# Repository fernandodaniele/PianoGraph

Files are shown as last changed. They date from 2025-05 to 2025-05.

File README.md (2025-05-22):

# PianoGraph 🎹
PianoGraph is an educational hardware device designed to assist beginners in learning to play the piano. Developed as a final thesis project for the Electronic Engineering degree in 2017, PianoGraph combines visual guidance and real-time feedback to enhance the learning process.
The system works by illuminating the keys a user should press, effectively acting as a visual tutor. This allows learners to associate musical notes with their physical positions on the keyboard, helping bridge the gap between reading sheet music and hand coordination.
PianoGraph was designed with accessibility and ease of use in mind, offering an intuitive interface and support for various practice modes. It aims to make learning the piano more engaging, effective, and fun.

## 📌 Features

- LED indicators above each key for real-time guidance  
- MIDI file support for learning actual songs  
- Multiple learning modes (note-by-note, tempo control, etc.)  
- Simple and intuitive user interface  
- Designed for acoustic and digital pianos  

## 🛠️ Technologies Used

- Microcontroller-based hardware  
- MIDI protocol for song input  
- LED driver circuits  
- Embedded C/C++  
- App for song management  

## 🚀 How It Works

1. Load a MIDI song file onto the app.  
2. PianoGraph analyzes the notes and lights up the corresponding keys.  
3. The learner follows the lights and plays the notes.  
4. Optional feedback features track progress and accuracy.

## Media
[https://youtu.be/cpoeSTIPf7A ](https://youtu.be/cpoeSTIPf7A)

## 📚 Academic Context

This project was completed in 2017 as a final thesis for the Electronic Engineering program. It represents a fusion of embedded systems, human-computer interaction, and music education.

## 📃 License

This project is open-source. See the `LICENSE` file for more details.

## ✉️ Contact

For more information or collaboration inquiries:  
[Fernando E. Daniele] 
[Gonzalo Velazquez]

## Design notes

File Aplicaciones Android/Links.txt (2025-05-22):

http://programandoointentandolo.com/2014/06/como-hacer-un-explorador-de-archivos-en-android.html

http://www.aprendeandroid.com/l8/listar_archivos.htm

http://jonsegador.com/2012/02/paso-de-datos-variables-entre-actividades-android/

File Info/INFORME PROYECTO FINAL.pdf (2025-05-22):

PROYECTO FINAL

Daniele, Fernando – Velazquez, Gonzalo |
PianoGraph! | | I

Autores: Daniele, Fernando.

Velazquez, Gonzalo.

Asignatura: Proyecto Final

Profesor: Ing. Daniel Musso

Institución: U.T.N. Facultad Regional

San Francisco.

Lugar: San Francisco, Córdoba

# PianoGraph!

Sistema virtual de aprendizaje de piano.

Daniele, Fernando – Velazquez, Gonzalo |
PianoGraph! | | II

Daniele, Fernando – Velazquez, Gonzalo |
PianoGraph! | | III

RESUMEN

Aprender a tocar un instrumento musical es una actividad que requiere de un

gran esfuerzo mental, similar al de aprender un nuevo idioma. Esto desde siempre

ha fascinado a gran parte de la población, sin importar su edad o ubicación

geográfica. Según datos del Instituto Nacional de Estadística y Geografía (México),

cerca del 30% de la población mexicana toca algún instrumento musical. Este

número asciende hasta casi un 50% en Austria, ubicándose el piano como el

segundo instrumento más tocado (después de la guitarra eléctrica).

En este proyecto, hemos desarrollado una herramienta para facilitar el proceso

de aprendizaje de un instrumento en específico, el piano. Mediante una

pantalla/cortina de ledes ubicada sobre las teclas del mismo, y haciendo uso de

señales lumínicas, el dispositivo le indicará al usuario cuales teclas debe presionar

en el instante preciso en que corresponda. Mediante un microcontrolador se

decodifica cualquier canción en formato MIDI que el usuario desee aprender, y se

muestra en el dispositivo. De esta forma el usuario puede ejecutar perfectamente

cualquier canción siguiendo las instrucciones. Al finalizar la canción el dispositivo

otorga un puntaje de éxito/error obtenido, con el fin de tener una medida para auto

superarse o competir con amigos.

Palabras claves propuestas: CORTINA LED, PANTALLA LED, MIDI, PIANO,

INSTRUMENTO MUSICAL, APRENDIZAJE.

Daniele, Fernando – Velazquez, Gonzalo |
PianoGraph! | | IV

ÍNDICE

RESUMEN | IIII
ÍNDICE | IV
INTRODUCCIÓN | 1
OBJETIVOS | 4
DESCRIPCIÓN | 5
METAS | 9
JUSTIFICACIÓN | 11
ASPECTOS DE MERCADO | 12
ASPECTOS INSTITUCIONALES | 15
CONTENIDO DEL PROYECTO | 14
CONCLUSIONES | 55
APENDICE | 56
BIBLIOGRAFÍA | 57
ANEXO I | 58
ANEXO II | 60

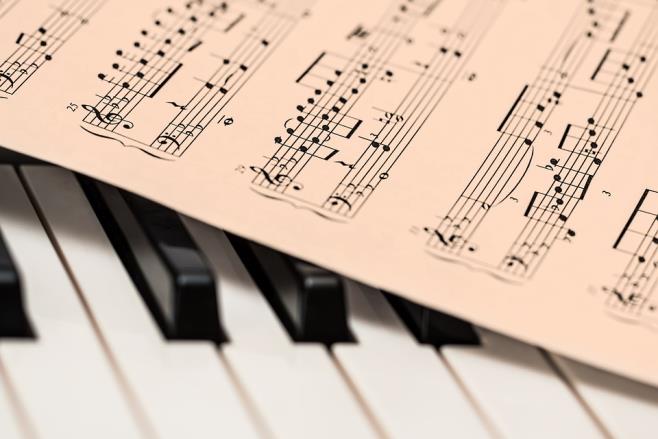
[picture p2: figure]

Ingeniería Electrónica | PianoGraph! | 1

INTRODUCCIÓN

Este proyecto nace de la necesidad personal de uno de nosotros de aprender a

tocar el piano, quien, al momento de hacerlo, se encontró con muchas dificultades,

principalmente por los actuales métodos de aprendizaje.

A grandes rasgos, existen dos métodos de aprender a ejecutar un instrumento

musical:

- Un primer método consiste en aprender la teoría musical, cómo están

compuestos los acordes, dónde se ubica cada nota en el teclado, y comenzar

a leer partituras simples, hasta eventualmente poder ejecutar partituras más

complejas. Este es un método que requiere gran dedicación y esfuerzo, ya

que se aprende verdaderamente música, se comprende lo que se está

tocando y se puede llegar a dominar el instrumento profesionalmente.

Fig.1

- Un segundo método consiste en observar a otra persona tocando la canción

deseada, memorizar cuales teclas presiona y copiar los movimientos. Esta es

una solución que no requiere de estudios ni aprendizaje de la teoría musical.

Presenta la ventaja de que en poco tiempo (quizás menos de un día), la

persona puede estar ejecutando perfectamente alguna pieza. La desventaja

es que se requiere de una solución específica para cada canción diferente

que la persona quiera aprender, ya que en cada canción se tocan diferentes

notas, la persona debe copiar diferentes movimientos.

Ingeniería Electrónica | PianoGraph! | 2

Este es un método ampliamente difundido en internet, donde se pueden

observar videos para aprender diferentes canciones, e incluso existen

aplicaciones dedicadas a este método, como Synthesia ®. Algunas personas

sólo desean poder tocar el piano sin dedicarse profesionalmente a ello, y ésta

es una solución adecuada para aprender a ejecutar canciones sin tener que

pasar quizás años estudiando música. Es por eso que optamos por

desarrollar un dispositivo que utilice este método para enseñar a los usuarios.

Fig.2 - Synthesia

El dispositivo a desarrollar constaría de una pantalla o cortina de ledes, con

tantas columnas de ledes como teclas tenga el piano/teclado. Estos ledes se

encenderán unos instantes antes del momento de que el usuario deba presionar la

nota, desde la primer fila (ubicada más alejada del piano), secuencialmente hasta la

última fila (ubicada lo más cerca de las teclas posible), que será el momento en que

se debe presionar dicha tecla.

Gracias a una interfaz y una metodología de juego sencilla cualquier persona,

de cualquier edad o educación podrá aprender a tocar el piano. Además, este

proyecto presenta un potencial enorme ya que no existe nada similar en el mercado.

Los videojuegos que utilizan el mismo principio, como Guitar Hero ® (en el que se

toca una guitarra con seis botones), o Pump It Up ® (una alfombra donde se

presionan unos indicadores luminosos con los pies al ritmo de la música), tuvieron

Ingeniería Electrónica | PianoGraph! | 3

gran aceptación y éxito, lo que indica que para las personas es fácil y divertido

entender la dinámica del juego.

Fig 3 y 4 – Videojuegos que utilizan el mismo principio

Una ventaja fundamental, es que el usuario no debería comprar un piano

específico para utilizar este sistema, sino que se puede adaptar a cualquier

piano/teclado existente.

Ingeniería Electrónica | PianoGraph! | 4

OBJETIVOS

La finalidad del proyecto es crear un dispositivo gracias al cual cualquier

persona, sin importar su edad o educación, sea capaz de aprender de manera

sencilla y divertida a tocar el piano, o instrumentos similares tales como el órgano o

teclado electrónico. El usuario debe ser capaz de elegir la melodía que desea tocar

mediante una computadora o celular. Los mismos deben estar conectados física o

inalámbricamente al dispositivo, el cual a través de una pantalla de diodos ledes

indicará en que momento presionar o soltar cada tecla del instrumento musical.

Podemos dividir el objetivo general en tres objetivos específicos:

1° Comprender el protocolo de comunicación MIDI, y a través de una conexión por

puerto MIDI mostrar las notas correspondientes en la cortina de ledes.

2° Realizar una retroalimentación desde el teclado electrónico hacia el dispositivo

para comparar lo tocado por el usuario con la melodía original.

3° Desarrollar un aplicación para celulares que realice una comunicación bluetooth

con el dispositivo para poder cargar las canciones a través del mismo y visualizar el

puntaje obtenido.

Ingeniería Electrónica | PianoGraph! | 5

DESCRIPCIÓN

El protocolo MIDI (Musical Instrument Digital Interface), es un tipo de

comunicación serial utilizado ampliamente por casi todos los instrumentos musicales

que posean la necesidad de intercambiar información entre ellos, (sintetizadores,

controladores, teclados, etc). Si tomamos como ejemplo un teclado electrónico que

tenga la posibilidad de recibir mensajes MIDI provenientes de otro instrumento o

computadora, y pueda reproducirlos por sus parlantes, lo que sucede para que ello

ocurra es lo siguiente:

1. El dispositivo emisor del mensaje envía mediante el cable MIDI una serie

de bytes, donde se encuentra especificado, por ejemplo, si es un mensaje

para encender una nota: el número de esa nota (del 0 al 127,

correspondiendo el 60 al do central de un piano), y la intensidad con la que

esa nota debe sonar (el volumen).

2. El teclado electrónico que reciba esos mensajes, tiene un banco de sonidos

almacenados, con un sonido diferente para cada una de las 128 notas

posibles, y reproducirá según indique el mensaje MIDI, una de estas notas,

hasta que llegue otro mensaje MIDI, que indique que el sonido debe cesar.

Cabe aclarar que en un mensaje MIDI no está especificado el tipo de sonido que

debe reproducirse, es decir, el dispositivo que reproduzca el sonido puede asignar el

timbre de una guitarra, de una flauta, o de cualquier instrumento que tenga cargado

en su base de datos al mensaje MIDI recibido.

De la misma manera que un teclado recibe y transforma esos mensajes MIDI a

sonido, PianoGraph! posee un microcontrolador que recibe y transforma los

mensajes MIDI en estímulos visuales (luces ledes) y asigna una columna de ledes a

cada número de nota recibido.

Cada columna se encuentra posicionada exactamente sobre cada tecla de un piano

estándar. Entonces al encenderse el primer Led de una columna, este comienza a

descender fila por fila, hasta llegar a la última fila, donde será el momento de

presionar la tecla indicada.

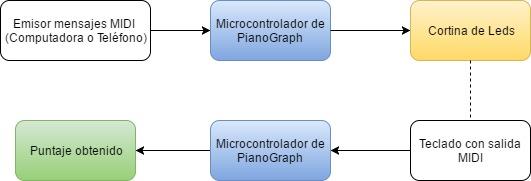
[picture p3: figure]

Ingeniería Electrónica | PianoGraph! | 6

Fig. 5 - Descripción

Las luces descenderán desde la primera fila hacia la última, desplazándose a

intervalos de tiempo iguales. Este intervalo puede ser ajustado por el usuario, cuanto

menor sea el tiempo de desplazamiento, más rápida será la velocidad con la que las

luces llegan hasta la última fila, con lo que el tiempo de reacción del usuario deberá

ser también menor. Al disminuir el tiempo de desplazamiento lo que se logra es

tener una mayor resolución de las notas de muy corta duración, a costo de disminuir

el tiempo total en que la nota se muestra en pantalla.

Por ejemplo, si suponemos que una nota dada tiene una duración tal que logra

encender 4 filas de ledes simultáneamente mientras se desplaza, al disminuir el

tiempo de desplazamiento a la mitad, lo que lograremos es que esa nota ahora

encienda 8 filas de ledes, pero el tiempo total en que la tecla del piano deberá ser

presionada permanece exactamente igual.

Ingeniería Electrónica | PianoGraph! | 7

Fig.6 – Notas iguales a distinta velocidad de desplazamiento

Una vez que las notas han sido indicadas por PianoGraph!, el microcontrolador

detectará si existe un teclado enviando datos mediante una conexión MIDI, para

lograr entonces realizar la comparación entre la nota mostrada y la tecla presionada,

obteniendo así mediante un algoritmo un porcentaje que representará la fidelidad

con la que fueron presionadas las notas en el teclado, como consecuencia final

entonces, la fidelidad con la que la canción fue ejecutada por el usuario.

Este puntaje será enviado mediante la conexión Bluetooth al teléfono desde donde

se estaban enviando las instrucciones MIDI (utilizando la apk desarrollada para el

mismo propósito), y será visualizada en pantalla inmediatamente al finalizar la

canción.

El envío de los mensajes MIDI que contienen las notas pertenecientes a las distintas

canciones que el usuario desee ejecutar se realiza mediante la aplicación para

dispositivos Android llamada también PianoGraph!. Esta aplicación establece una

conexión Bluetooth entre el celular y el dispositivo para poder envíar las

instrucciones MIDI.

Ingeniería Electrónica | PianoGraph! | 8

METAS

Para evaluar el avance de nuestro proyecto, los puntos a cubrir deberían ser:

### 1. Lograr controlar una alta cantidad de ledes con una única unidad

microcontroladora (podrían llegar a ser más de 1000 ledes que operen de

manera independiente cada uno).

Una vez que se haya logrado el multiplexado y desarrollados los algoritmos

pertinentes para controlar eficazmente esa cantidad de diodos, se podría proceder a

la segunda parte del proyecto.

### 2. Desarrollar un algoritmo capaz de interpretar los mensajes MIDI y

transformarlos en instrucciones para encender los ledes correspondientes.

Cuando el microcontrolador sea capaz de entender un mensaje MIDI (inicialmente

enviado a través de cables, directamente desde un instrumento MIDI), y asignar a

cada columna de ledes, una nota recibida, el próximo paso sería automatizar el

envío de estas instrucciones.

### 3. Desarrollar una aplicación móvil que sea capaz de interpretar archivos MIDI

(el formato en que deberían encontrarse las canciones a aprender), y enviarlos al

microcontrolador.

Consiste en programar mediante el entorno de programación “Android Studio”, una

aplicación capaz de comunicarse con PianoGraph!, e interpretar archivos MIDI

descargados desde internet.

### 4. Establecer una comunicación inalámbrica entre el teléfono y la cortina de

ledes.

Este paso estará finalizado cuando podamos conectarnos y desconectarnos a

voluntad, desde un dispositivo móvil a PianoGraph!, y poder repetir el proceso

desde cualquier otro dispositivo.

5. Realimentar el microcontrolador de la cortina con las notas del piano,

compararlas con las notas que debían ser presionadas, y enviar al teléfono un

valor de error/acierto.

Ingeniería Electrónica | PianoGraph! | 9

JUSTIFICACIÓN

Actualmente, una de las aplicaciones más utilizadas para aprender el manejo del

piano es Synthesia (con más de un millón de descargas en Google PlayStore).

Posee una interfaz sencilla, rápida y amigable para el usuario. Además de

proporcionar un método de enseñanza altamente gráfico y efectivo.

Fue por eso, que al ver un producto tan ampliamente aceptado como lo fue

Synthesia, sentimos que podíamos seguir el mismo camino y mejorar aún más este

método de enseñanza. No existe actualmente ningún producto con características

similares a PianoGraph!. Los softwares como Synthesia presentan la gran

desventaja que dependen del tamaño del dispositivo en donde sean ejecutadas. Al

ver las notas presionadas en un teléfono de quizás 5 pulgadas, se pierde la

perspectiva al tratar de ubicarlas rápidamente en un piano de cerca de un metro de

ancho.

Por eso consideramos que PianoGraph! presenta una ventaja fundamental sobre

todas estas aplicaciones, y que su comercialización es posible internacionalmente.

No es ningún secreto que el piano es uno de los instrumentos más tocados y más

difundidos a lo largo del planeta, por lo que estamos frente a un mercado

considerablemente amplio.

Ingeniería Electrónica | PianoGraph! | 10

ASPECTOS DE MERCADO

Al ser un producto que requiere un bajo costo de producción, poco instrumental, y

poco tiempo de fabricación, sería posible manufacturarlo de manera personal, en un

espacio relativamente reducido, tal vez tercerizar los elementos que requieran una

calidad visual especial (como el soporte o la cortina), ensamblarlo y comercializarlo

por internet, sin la necesidad de un local físico donde se presente al público.

Esperamos que la demanda crezca exponencialmente con el paso del tiempo, a

medida que las personas conozcan la existencia del producto.

Creemos que este producto tendrá un impacto mayor sobre los jóvenes, es por eso

que nuestra publicidad estaría fuertemente enfocada a las redes sociales, cuyo

alcance trasciende fronteras y puede ser visualizado por personas de cualquier parte

del mundo en instantes. Además, al ser los costos de producción relativamente

bajos, sería posible su comercialización a un precio razonable, posibilitando la aún

más rápida difusión del producto (mientras más personas lo posean, más personas

conocerán la existencia del producto).

Ingeniería Electrónica | PianoGraph! | 11

ASPECTOS FINANCIEROS

Para la realización de este proyecto se necesitó la compra de diversos materiales, obtenidos

en mercados locales, que están detallados a continuación:

Componentes para placa PCB:

CANTIDAD | TIPO | VALOR
1 | CONECTOR TRANSFORMADOR
1 | LED VERDE 5MM
1 | OPTOACOPLADOR | 6N136
1 | DIODO PROTECCION | 1N4001
1 | C1 | 100pF
1 | C2 | 100pF
1 | RD2 | 1K
1 | REGULADOR | 7805
1 | R MIDI1 | 220
1 | R MIDI 2 | 470
1 | R MIDI 3 | 10K
1 | DIODO MIDI 1 | 1N4148
1 | TRANSISTOR MIDI Q1 | BC547
1 | ATMEGA 2560
1 | CM1 | 22p
1 | CM2 | 100n
1 | CM3 | 100n
1 | CM4 | 100n
1 | CM5 | 100n
1 | CM6 | 100n
1 | RM1 | 10K
1 | XTAL | SPK16.000G
2 | CXTAL | 22 pF
1 | R XTAL | 1M
1 | RXTAL | 27 Ω
1 | SWITCH BOTON
1 | DIODO M 1 | 1N4001
6 | CONECTORES HEMBRA | 2X8
12 | CONECTORES MACHO | 2x8
2 | TIRA DE 40 PINES

Fig. 7

Ingeniería Electrónica | PianoGraph! | 12

Componentes para ensamblado y desarrollo:

Placa desarrolladora Arduino Mega | 390
Circuitos Optoacopladores | 60
Madera | 40
Plástico para impresora 3D | 20
Conversor MIDI-USB | 200
Placas para PCB | 410
Separadores | 60
Vinilo Polarizado | 26
Módulo Bluetooth | 150
Caños | 189
Bulones y tornillos | 100
LED | 1050
Cables + conectores | 300
Manufacturación de prototipos de PCB | 2000
TOTAL | 4995

Fig. 8

El diseño del primer prototipo tuvo un costo aproximado de $5000 pesos, aunque

confiamos en que, una vez iniciada la producción, los costos se reducirán

considerablemente debido a la compra en cantidad de insumos, y a una mejor

selección de proveedores.

Ingeniería Electrónica | PianoGraph! | 13

ASPECTOS INSTITUCIONALES

No existe una institución que realice o financie este proyecto, los únicos

responsables del mismo somos los autores del presente trabajo.

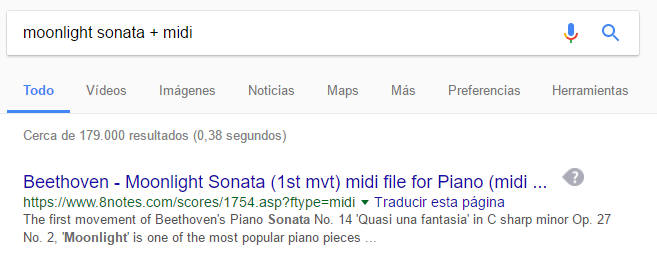
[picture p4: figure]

Ingeniería Electrónica | PianoGraph! | 14

CONTENIDO DEL PROYECTO

Fig. 9

Para poder utilizar este dispositivo, en primer lugar, debemos saber qué canción

deseamos aprender a tocar en el piano. A modo de ejemplo, vamos a suponer que

deseamos aprender a tocar la canción “Moonlight Sonata” de “Beethoven”.

Entonces debemos conseguir el archivo en formato MIDI que contenga las

instrucciones a interpretar por PianoGraph!.

En internet se puede encontrar prácticamente cualquier canción en este formato

simplemente ingresando en un buscador web el título de la canción deseada

acompañado de la palabra “MIDI”.

Fig. 10 – Búsqueda en Google.

Ingeniería Electrónica | PianoGraph! | 15

En este caso, clickeamos en la primera página web (www.8notes.com) y seguimos

las instrucciones para descargar el archivo.

Entonces ya tenemos el archivo, pero…

- ¿Qué es un archivo MIDI?:

Las siglas MIDI son una abreviatura de Musical Instrument Digital Interface. Se trata

de un protocolo de comunicación que apareció en el año 1982, fecha en la que

distintos fabricantes de instrumentos musicales electrónicos se pusieron de acuerdo

en su implementación. Aunque originalmente se concibió como un medio para poder

interconectar distintos sintetizadores, el protocolo MIDI se utiliza actualmente en una

gran variedad de aplicaciones: grabación musical, cine, TV, ordenadores

domésticos, presentaciones multimedia, etc.

Dado que este protocolo es bastante eficiente en cuanto a enviar cantidades de

datos relativamente grandes a una velocidad respetable, se ha convertido en un

elemento de gran utilidad para compositores, educadores, programadores y gente

que intenta crear música con varios instrumentos. Con la ayuda de un ordenador o

un secuenciador hardware, permite crear arreglos multipistas, líneas o partes

instrumentales, etc.

Veamos de forma un poco más precisa algunas de las ventajas que proporciona:

Generar sonido a partir de un sintetizador MIDI en vez de hacerlo partiendo de un

sampler tiene algunas ventajas. La primera de ellas es que se necesita una gran

cantidad de espacio de almacenamiento para guardar el audio muestreado (p.ej., en

forma de archivos .WAV o AIFF).

Se necesitan unos 10 Mb de espacio en disco para almacenar 1 minuto de audio

estéreo muestreado en calidad CD (16 bits y 44,1kHz). En comparación, los archivos

de datos MIDI tienen un tamaño insignificante. Una secuencia MIDI típica utiliza sólo

unos 10 Kb por minuto.

¿Y cómo funciona?

El archivo MIDI no contiene datos de audio muestreado, sino más bien una serie de

instrucciones que el sintetizador u otro generador de sonido utiliza para reproducir el

Ingeniería Electrónica | PianoGraph! | 16

sonido en tiempo real. Estas instrucciones son mensajes MIDI que indican al

instrumento qué sonidos hay que utilizar, qué notas hay que tocar, el volumen de

cada una de ellas, etc.

Otras ventajas:

Ofrece la posibilidad de editar la música con facilidad.

Permite alterar la velocidad de reproducción y la altura tonal de los sonidos de forma

independiente.

¿Cómo está compuesto un mensaje MIDI?

Un mensaje MIDI es una secuencia de bytes que contienen información sobre qué

tipo de mensaje se está transmitiendo (ya sea un comando o un dato), y datos

referentes a la nota que se debe ejecutar. Estos datos se transmiten entre los

instrumentos musicales, con una tasa de baudios de 31.250.

Fig. 11 – Mensaje MIDI

Entonces podemos observar que por ejemplo para un mensaje de “Nota ON” (que

empiece a reproducirse una nota dada en el instrumento objetivo), se utilizarán 3

bytes. El primer byte indicará que es una instrucción, utilizando los primeros 4 bits

para definir de cuál de todas las instrucciones se trata, y los últimos 4 bits indicarán

en cuál de los 16 canales disponibles (se pueden manejar hasta 16 instrumentos

diferentes) debe reproducirse dicha instrucción.

El byte siguiente indicará qué nota se debe encender, y el último indicará la

velocidad con la que debe presionarse (intensidad o volumen). Con el protocolo MIDI

se pueden manejar hasta 128 diferentes notas, más que suficiente para cualquier

instrumento (el piano con mayor cantidad de notas actualmente posee 96 teclas).

En la siguiente tabla se pueden observar los números asignados a cada nota. Cabe

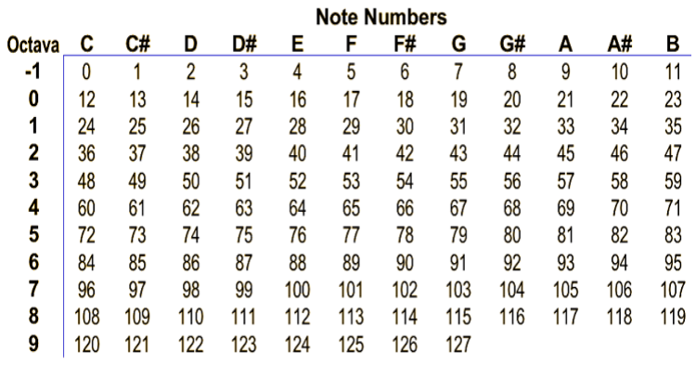
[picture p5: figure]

Ingeniería Electrónica | PianoGraph! | 17

aclarar que en la tabla las notas se encuentran designadas con cifrado americano.

Do | Re | Mi | Fa | Sol | La | SI
C | D | E | F | G | A | B

Fig. 12 - (Traducción del cifrado latino a cifrado americano)

Fig. 13 – Número de notas

Otra aclaración es que según la teoría musical, existen 12 notas en la escala

cromática, ya que 5 de las 7 notas naturales presentan una nota intermedia, llamada

sostenido, o bemol, dependiendo de la escala que se esté utilizando. Cada grupo de

12 notas se denomina “Octava”, nuestro dispositivo fue diseñado para contener 5

Ingeniería Electrónica | PianoGraph! | 18

octavas (60 notas), existiendo la posibilidad de anexar más octavas si se desease.

Fig. 14 – Parámetros MIDI

En la tabla anterior podemos observar distintos tipos de comandos que pueden ser

enviados en formato MIDI. Y en la tabla siguiente podemos observar con qué código

se identifica cada comando (el primer byte). Para el uso de nuestro dispositivo, sólo

nos interesan los comandos “Nota ON” y “Nota OFF”, es por eso que la aplicación

diseñada para interpretar los archivos MIDI, está diseñada para ignorar el resto de

los comandos, junto a sus parámetros respectivos.

1000XXXX = Note off

1001XXXX = Note on

1010XXXX = Aftertouch

1011XXXX = Continuous controller

1100XXXX = Patch change

1101XXXX = Channel pressure

1110XXXX = Pitch bend

1111XXXX = Non-musical commands

Fig. 15 – Instrucciones MIDI

Ingeniería Electrónica | PianoGraph! | 19

El protocolo de comunicación MIDI se basa en el protocolo Serial Asíncrono.

Cuando se opera en modo asíncrono no existe una línea de reloj común que

establezca la duración de un bit y el caracter puede ser enviado en cualquier

momento. Esto conlleva que cada dispositivo tiene su propio reloj y que previamente

se ha acordado que ambos dispositivos transmitirán datos a la misma velocidad.

No obstante, en un sistema digital un reloj es normalmente utilizado para sincronizar

la transferencia de datos entre las diferentes partes del sistema. El reloj definirá el

inicio y fin de cada unidad de información, así como la velocidad de transmisión. Si

no existe reloj común, algún modo debe ser utilizado para sincronizar el mensaje.

En realidad, la frecuencia con que el reloj muestrea la línea de comunicación es

mucho mayor que la cadencia con que llegan los datos. Por ejemplo, si los datos

están llegando a una cadencia de 2400 bps, el reloj examinará la línea unas 19200

veces por segundo, es decir, ocho veces la cadencia binaria. La gran rapidez con

que el reloj muestrea la línea permite al dispositivo receptor detectar una transmisión

de 1 a 0 o de 0 a 1 muy rápidamente, y mantener así la mejor sincronización entre

los dispositivos emisor y receptor.

El tiempo por bit en una línea en que se transfiere la información a 2400 bps es de

unos 416 microsegundos (1 seg/2400). Una frecuencia de muestreo de 2400 veces

por segundo nos permitirá muestrear el principio o el final del bit. En ambos casos

detectaremos el bit, sin embargo, no es extraño que la señal cambie ligeramente, y

permanezca la línea con una duración un poco más larga o más corta de lo normal.

Por todo ello, una frecuencia de muestreo lenta no sería capaz de detectar el cambio

de estado de la señal a su debido tiempo, y esto daría lugar a que la estación

terminal no recibiera los bits correctamente.

Bit de inicio y bit de parada

En la transmisión asíncrona un caracter a transmitir es encuadrado con un indicador

de inicio y fin de carácter, de la misma forma que se separa una palabra con una

letra mayúscula y un espacio en una oración. La forma estándar de encuadrar un

carácter es a través de un bit de inicio y un bit de parada.

Ingeniería Electrónica | PianoGraph! | 20

Durante el intervalo de tiempo en que no son transferidos caracteres, el canal debe

poseer un "1" lógico. Al bit de parada se le asigna también un "1". Al bit de inicio del

carácter a transmitir se le asigna un "0". Por todo lo anterior, un cambio de nivel de

"1" a "0" lógico le indicará al receptor que un nuevo carácter será transmitido.

Reglas de transmisión asíncrona

La transmisión asíncrona que vamos a ver es la definida por la norma RS232, que

se basa en las siguientes reglas:

a. Cuando no se envían datos por la línea, ésta se mantiene en estado alto (1).
b. Cuando se desea transmitir un carácter, se envía primero un bit de inicio que

pone la línea a estado bajo (0) durante el tiempo de un bit.

c. Durante la transmisión, si la línea está a nivel bajo, se envía un 0 y si está a

nivel alto se envía un 1.

d. A continuación, se envían todos los bits del mensaje a transmitir con los

intervalos que marca el reloj de transmisión. Por convenio se transmiten entre

5 y 8 bits.

e. Se envía primero el bit menos significativo, siendo el más significativo el

último en enviarse.

f. A continuación del último bit del mensaje se envía el bit (o los bits) del final

que hace que la línea se ponga a 1 por lo menos durante el tiempo mínimo de

un bit. Estos bits pueden ser un bit de paridad para detectar errores y el bit o

bits de stop, que indican el fin de la transmisión de un carácter.

Los datos codificados por esta regla pueden ser recibidos siguiendo los pasos

siguientes:

a. Esperar la transición 1 a 0 en la señal recibida.
b. Activar el reloj con una frecuencia igual a la del transmisor.
c. Muestrear la señal recibida al ritmo de ese reloj para formar el mensaje.
d. Leer un bit más de la línea y comprobar si es 1 para confirmar que no ha

habido error en la sincronización.

Ingeniería Electrónica | PianoGraph! | 21

Velocidad de transmisión

En la transmisión asíncrona por cada caracter se envía al menos 1 bit de inicio y 1

bit de parada así como opcionalmente 1 bit de paridad. Esta es la razón de que los

baudios no se correspondan con el número de bits de datos que son transmitidos.

La característica fundamental del formato de transmisión asíncrono es su capacidad

de manejar datos en tiempo real, con un intervalo de longitud arbitraria entre

caracteres sucesivos. Al final de cada caracter, la línea va a 1 en el bit de parada y

permanece en ese estado durante un número arbitrario de bits ociosos. El inicio del

nuevo caracter estará definido por la transición a 0 del bit de inicio.

- Optoacoplador:

Si bien el protocolo MIDI está basado en la comunicación Serial asíncrona, también

presenta algunas diferencias que hacen imposible (o poco recomendado) acoplarlo

directamente a un dispositivo que utilice el protocolo Serial TTL.

La diferencia fundamental, es que un dispositivo que utiliza el protocolo TTL, utiliza

diferentes niveles de tensión para identificar los 1 y los 0 lógicos (0V y 5V

respectivamente), mientras que un dispositivo MIDI utiliza valores de corriente para

el mismo objetivo (0mA y 20mA).

Es por eso que se recomienda aislar eléctricamente ambos dispositivos mediante el

uso de un optoacoplador.

Un optoacoplador, también llamado optoaislador o aislador acoplado ópticamente,

es un dispositivo de emisión y recepción que funciona como un interruptor activado

mediante la luz emitida por un diodo led que satura un componente optoelectrónico,

normalmente en forma de fototransistor o fototriac. De este modo se combinan en un

solo dispositivo semiconductor, un fotoemisor y un fotorreceptor cuya conexión entre

ambos es óptica. Estos elementos se encuentran dentro de un encapsulado que por

lo general es del tipo DIP. Se suelen utilizar para aislar eléctricamente a dispositivos

muy sensibles.

Ingeniería Electrónica | PianoGraph! | 22

Fig. 16 – Esquema Optoacoplador

Como la velocidad de transmisión de 31250 baudios requiere una buena respuesta

en frecuencia del transistor interno del optoacoplador, hemos utilizado el circuito

integrado 6N136 para este proyecto, ya que presenta buenas prestaciones en alta

frecuencia.

En las siguientes imágenes podemos observar la diferencia en el mensaje recibido

por 3 diferentes optoacopladores (dos de ellos con mala respuesta en alta

frecuencia, y otro, el dispositivo elegido).

Fig. 17 – Mensaje original, utilizando el optoacoplador 6N136

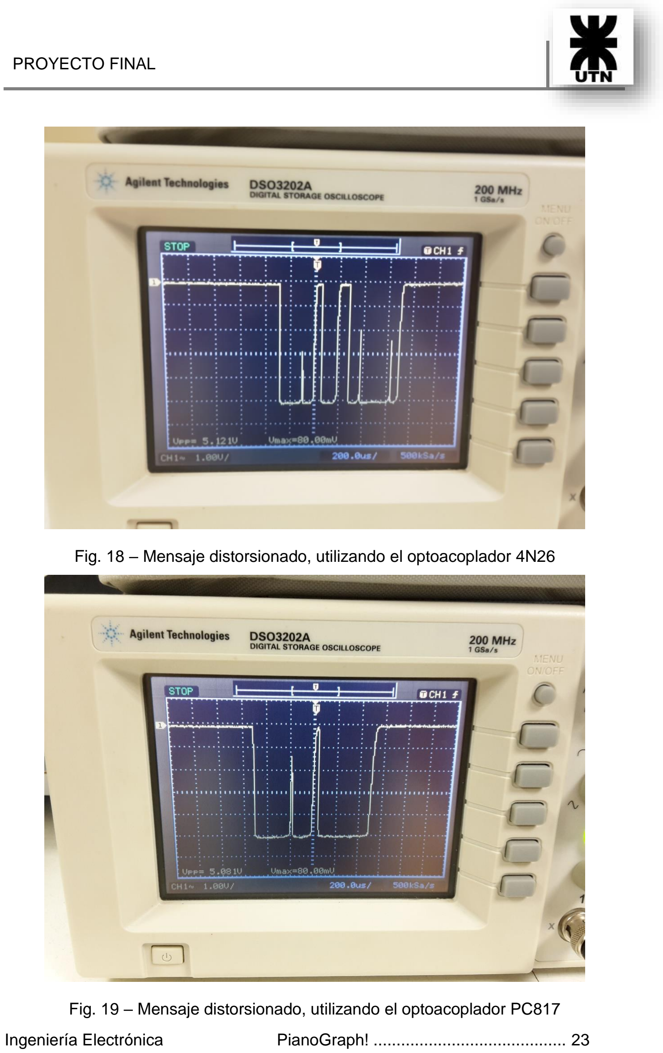
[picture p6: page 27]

Ingeniería Electrónica | PianoGraph! | 23

Fig. 18 – Mensaje distorsionado, utilizando el optoacoplador 4N26

Fig. 19 – Mensaje distorsionado, utilizando el optoacoplador PC817

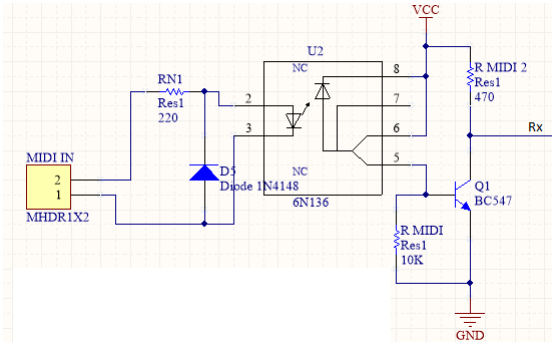
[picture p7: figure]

Ingeniería Electrónica | PianoGraph! | 24

Una vez hechas las pruebas pertinentes respecto a la velocidad de respuesta del

dispositivo elegido, diseñamos el circuito esquemático y luego, la placa PCB para

integrar dentro de la placa final donde montaremos también el microcontrolador.

Fig. 20 – Circuito esquemático Acoplador MIDI-TTL

- Pantalla Led

Para que el usuario comprenda qué teclas del piano debe presionar, diseñamos un

arreglo de ledes de tal manera que sobre cada tecla del instrumento se sitúe una

columna de 16 ledes separados 1cm uno de otro.

Estos ledes se encenderán momentos antes que el usuario deba presionar dicha

tecla, comenzando por el diodo más alejado de la nota a tocar, y encendiéndose uno

a uno, hasta llegar a la luz más cercana a la tecla, que será el momento en que el

usuario debe presionar dicha tecla.

Para la construcción de esta pantalla, construimos 5 módulos idénticos de 12x16

ledes. Cada módulo representa una octava entera (las 12 notas de la escala).

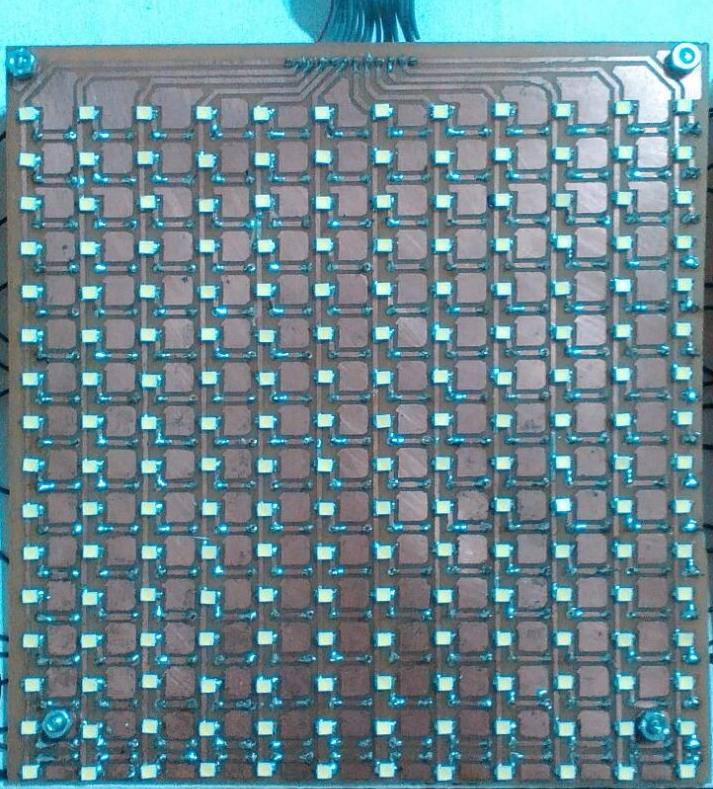
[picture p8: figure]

Ingeniería Electrónica | PianoGraph! | 25

Decidimos utilizar este método modular ya que existen teclados conformados desde

2 octavas hasta 8, entonces para evitar tener que construir un dispositivo para cada

opción, simplemente el usuario debe decidir cuántas octavas desea y anexar tantos

módulos como octavas precise.

Fig. 21 – Módulo de una octava, 192 ledes

Cada módulo presenta un total de 28 entradas, 12 superiores, y 16 laterales, con las

que con sólo 28 cables se puede controlar independientemente un total de 192 ledes

diferentes.

Ingeniería Electrónica | PianoGraph! | 26

Además, al anexar cada módulo junto al otro, los 16 cables laterales son

compartidos, es decir que, por cada octava añadida, el microcontrolador sólo debe

disponer de 12 nuevas salidas.

Otra ventaja de este método es que, para encender los ledes, hacemos uso de un

multiplexado, por lo que sólo una fila está encendida a la vez, reduciendo el

consumo hasta 16 veces lo que consumiría si se encendieran todas las luces

simultáneamente. Al utilizar un circuito integrado multiplexador, no es necesario

entonces que los 16 cables laterales provengan del microcontrolador, sino que

podemos utilizar un número en binario del 0 al 16, que indique secuencialmente qué

fila debe ser encendida. Esto fue de hecho lo que hemos realizado, reduciendo la

cantidad de salidas necesarias de parte del microcontrolador de 16 a sólo 4.

Finalmente podemos decir que se necesitan 4 salidas del microcontrolador, y 12

más por cada octava que contenga la pantalla.

Ingeniería Electrónica | PianoGraph! | 27

Fig. 22 – Circuito final de un módulo de octava

Una vez conectados todos los módulos necesarios (en nuestro caso utilizamos 5

octavas), procedemos a los cálculos electrónicos para diseñar los circuitos que

manipulen esa gran cantidad de ledes (960 diodos) de la manera más eficiente

posible.

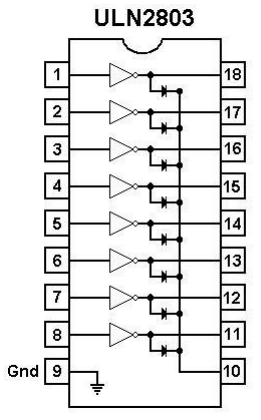
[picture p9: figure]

Ingeniería Electrónica | PianoGraph! | 28

Fig. 23 – Conexión de 5 módulos montados sobre soporte de madera

Para manejar la corriente de los ledes utilizamos dos integrados ULN2803 que son

drivers de corriente para 8 salidas. Utilizando dos de ellos podemos alimentar a las

16 filas de luces.

Fig. 24 – Esquema de ULN2803

Según la hoja de datos del led, la condición normal de funcionamientos se da con

una tensión directa de 3 V y consume 20 mA. Como alimentamos la placa con 5V,

es necesario utilizar una resistencia de 100 Ohms para limitar la corriente en cada

fila de ledes.

Ingeniería Electrónica | PianoGraph! | 29

R =

5 V − 3 V
20 mA = 100 Ω

Fig. 25

Estas resistencias estarían ubicadas en serie con cada fila, inmediatamente después

de los drivers de corriente.

Para manipular las 16 entradas de los drivers y, por ende las 16 filas de ledes,

hemos utilizado un decodificador CD74HC4514 de 4 a 16 líneas, manejado por un

microcontrolador. De esta forma cada fila se habilitará una a la vez, durante un

intervalo de tiempo pequeño, para lograr una velocidad que supere el tiempo de

respuesta de la vista humana y lograr el efecto de visual de que todos los ledes

estén prendidos al mismo tiempo.

Fig. 26 – Pinout CD74HC4514

El circuito final entonces, utilizando todos los componentes antes dichos, quedaría

construido de la siguiente manera.

Ingeniería Electrónica | PianoGraph! | 30

Fig. 27 – PCB circuito de control de filas.

Para controlar el encendido de cada Led, el sistema funciona de la siguiente

manera:

a. Supongamos que enumeramos las 60 columnas de ledes, siendo la

primera la columna número 1, y la última la número 60.

b. Supongamos también, que enumeramos las 16 filas, utilizando la letra “a”

para la fila superior, y la letra “ñ” para la última.

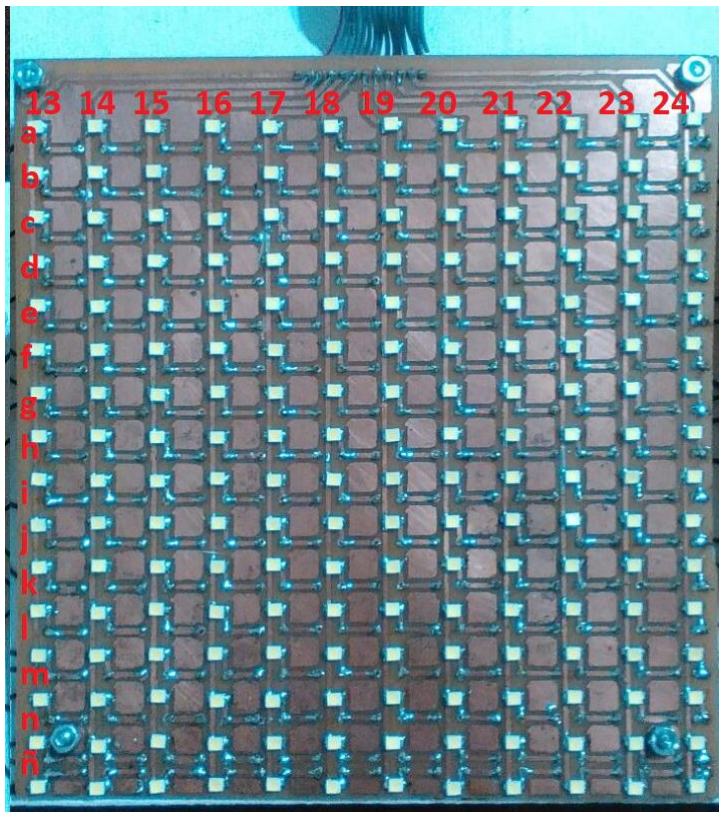
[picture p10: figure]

Ingeniería Electrónica | PianoGraph! | 31

Fig. 28 – Matriz de ledes

c. Sabemos que en condiciones normales todos los ledes se encuentran

apagados. Esto se logra aplicando tensión inversa a los terminales, es decir,

las salidas del microcontrolador correspondientes a los cables superiores (que

controlan las columnas) se encuentran en un estado lógico bajo, mientras que

las salidas del decodificador, (y conjuntamente de los drivers de corriente) se

encuentran en estado lógico alto. En estas condiciones es imposible que

ningún Led se encuentre encendido.

d. Si deseamos entonces, encender el diodo correspondiente a la posición

“24f” lo que debemos hacer es en primer lugar poner en un estado lógico Alto

(5V) la salida del microcontrolador correspondiente a la columna 24.

Ingeniería Electrónica | PianoGraph! | 32

Fig. 29 – Matriz de ledes

Este proceso aún no encenderá ningún Led, ya que ahora ambos terminales

de los diodos de toda la columna 24, se encuentran al mismo potencial. A

diferencia de los diodos de las demás columnas, que se encuentran

polarizados inversamente.

e. A continuación, debemos cambiar el estado de la fila “f” a 0V, logrando

entonces que sólo el diodo correspondiente a la posición “24f” esté polarizado

directamente y se encienda.

Ingeniería Electrónica | PianoGraph! | 33

Fig. 30 – Matriz de ledes

Cabe aclarar que todos los diodos de la columna 24 excepto el 24f poseen

sus dos terminales a 5V (haciendo imposible su encendido), y todos los

diodos de la fila “f” poseen ambas terminales a 0V, impidiendo también su

encendido, con excepción del diodo correspondiente a la columna 24.

Este proceso se repetirá de la misma manera para todos los ledes que sea

necesario encender.

Debido a que el microcontrolador puede cambiar el estado de todas sus

salidas simultáneamente, es posible encender todos los ledes de una fila sin

necesidad de multiplexar uno por uno. Por el contrario, el decodificador sólo

puede activar una salida a la vez, por lo que es obligatorio el multiplexado de

las filas una a una. Al hacerlo a una velocidad menor a una décima de

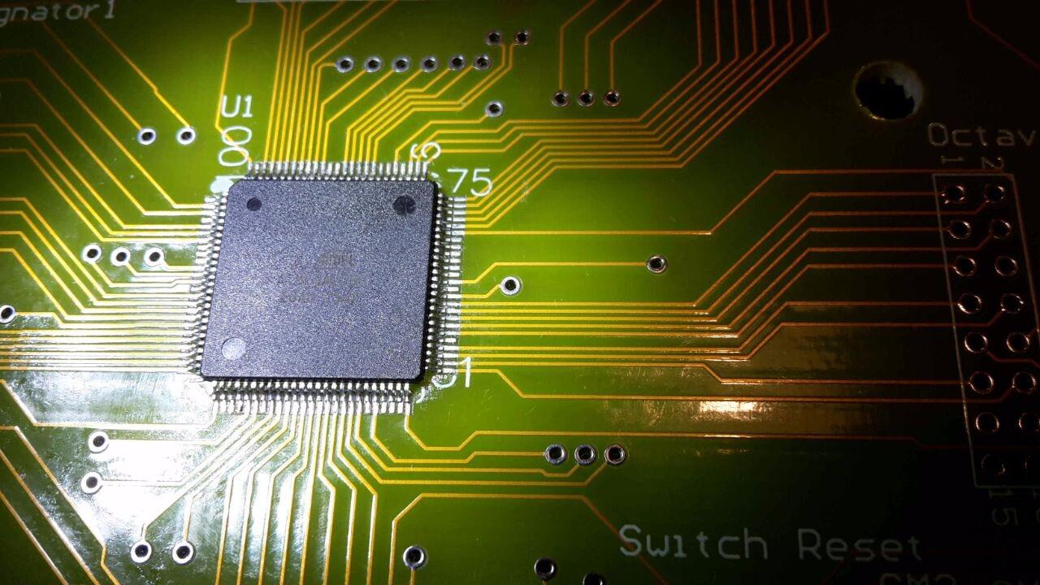
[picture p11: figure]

Ingeniería Electrónica | PianoGraph! | 34

segundo, el parpadeo de los ledes se vuelve imperceptible para el ojo,

creando un efecto óptico en el que pareciese que todas las luces están

encendidas a la vez. Esto se llama “Persistencia de la visión” (ver anexo).

- Microcontrolador

Una vez enviados los mensajes MIDI, estos deben ingresar a un microcontrolador

que los reciba, interprete y ejecute las acciones correspondientes para iluminar los

ledes indicados en la pantalla en el momento exacto que esto deba suceder.

Para ello hemos utilizado el microcontrolador ATMega2560.

Fig. 31 – Microcontrolador ATmega2560 en PianoGraph!

Este microcontrolador de 8 bits posee 256KBytes de memoria Flash programable, y

87 salidas/entradas digitales, lo que lo hace ideal para nuestro propósito, ya que

necesitamos 68 en total: 12 salidas por cada octava (lo que da un total de 60), 4

pines para la comunicación serial con los dispositivos MIDI (tanto el bluetooth que

envía las instrucciones de la canción, como la realimentación opcional del teclado,

para comparar las notas presionadas y otorgar un resultado de éxito/error), y 4

salidas más para manipular un decodificador de 4 a 16 salidas, para realizar el

Ingeniería Electrónica | PianoGraph! | 35

multiplexado de la pantalla y dar la sensación de que todos los ledes están

encendidos a la vez.

Fig. 32 – Pinout ATmega2560

Este microcontrolador tendrá que ejecutar diversas tareas simultáneamente. Debido

a su costo, velocidad, y capacidad de procesamiento fue el elegido para darle vida a

nuestro proyecto.

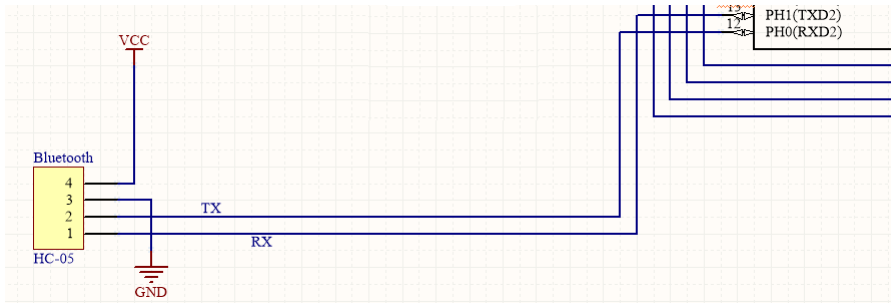
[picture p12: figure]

Ingeniería Electrónica | PianoGraph! | 36

El microcontrolador deberá establecer una comunicación Bluetooth con el dispositivo

que enviará el archivo MIDI a través de la aplicación desarrollada específicamente

para este proyecto.

Para ello hemos asignado uno de los 3 puertos Seriales que ATMega2560

exclusivamente para “escuchar” los datos provenientes del dispositivo Bluetooth.

Fig. 33 – Bluetooth HC-06

Los pines de Transmisión y Recepción serial (Tx y Rx) se encuentran ubicados en la

posición 12 y 13 respectivamente.

En toda comunicación serial entre dos dispositivos que presenten estos pines (Tx y

Rx) es necesario comunicarlos inversamente, es decir, unir mediante cables el pin

de transmisión de un dispositivo, con el de recepción del otro, y viceversa.

Para este proyecto, decidimos utilizar el módulo Bluetooth HC-06, debido a que es

un dispositivo simple de utilizar, sólo requiere alimentación y establecer la

comunicación serial mediante 2 pines (Tx y Rx). Además, generalmente no es

necesaria ninguna configuración, sólo se conecta y comienza a funcionar. No

obstante, el mismo fue configurado para trabajar a una velocidad de 115200 baudios

y le modificamos su nombre para que muestre “PianoGraph!” al ser encontrado por

otro dispositivo Bluetooth.

Ingeniería Electrónica | PianoGraph! | 37

Fig. 34 – Bluetooth HC-06

Para establecer la comunicación Bluetooth con el módulo HC-06 desde un

dispositivo Android simplemente es necesario encender el Bluetooth desde el

dispositivo, abrir la aplicación “PianoGraph!”, y seleccionarlo entre la lista de

dispositivos disponibles. Una vez realizado este paso, el módulo está listo para

recibir información y transmitirla al microcontrolador.

Fig. 35

Una segunda función que deberá desempeñar el microcontrolador es la de

interpretar y discriminar entre los mensajes recibidos que correspondan a mensajes

Ingeniería Electrónica | PianoGraph! | 38

MIDI para ejecutar en la pantalla Led, y los mensajes que no se apliquen a este fin y

deban ser ignorados.

Fig. 36

Como tercera función, el microcontrolador deberá desempeñar la tarea de encender

las luces de la pantalla led, alternando el estado lógico de 16 salidas digitales

correspondientes a las filas y activar o desctivar las columnas correspondientes a

cada fila encendida en ese momento.

Como cuarta función, el microcontrolador también presenta una entrada MIDI,

mediante la cual es posible conectar la salida MIDI (si es que posee) del

teclado/piano que se esté tocando.

El microcontrolador “escuchará” también las instrucciones MIDI enviadas por el

teclado, y comparará estas instrucciones con el estado de la última fila de la pantalla

led, si dicha fila indica que una nota “x” debe estar encendida, y del teclado llega la

instrucción que esa nota está siendo presionada, se añadirá puntaje a una variable

de éxito.

Si el caso inverso sucede, (hay que presionar una tecla y no está siendo presionada,

o hay una tecla presionada que no había que presionar), se incrementará una

variable de error.

El puntaje final será obtenido como porcentaje de puntos correctos entre puntos

totales.

Fig. 37

Ingeniería Electrónica | PianoGraph! | 39

Al finalizar la canción, la aplicación Android está diseñada para enviar una

instrucción no utilizada por los comandos MIDI, para indicarle al microcontrolador

que la melodía finalizó y que debe devolver el puntaje final.

El microcontrolador devolverá entonces a través del módulo Bluetooth, un dato

indicando el puntaje obtenido, calculado mediante un algoritmo que otorgará un

número comprendido entre el 0% de aciertos y el 100%.

La programación del microcontrolador se realizó en lenguaje C y a continuación se

muestran los diagramas de flujo del código correspondiente:

Ingeniería Electrónica | PianoGraph! | 40

Fig. 38 – Rutina principal

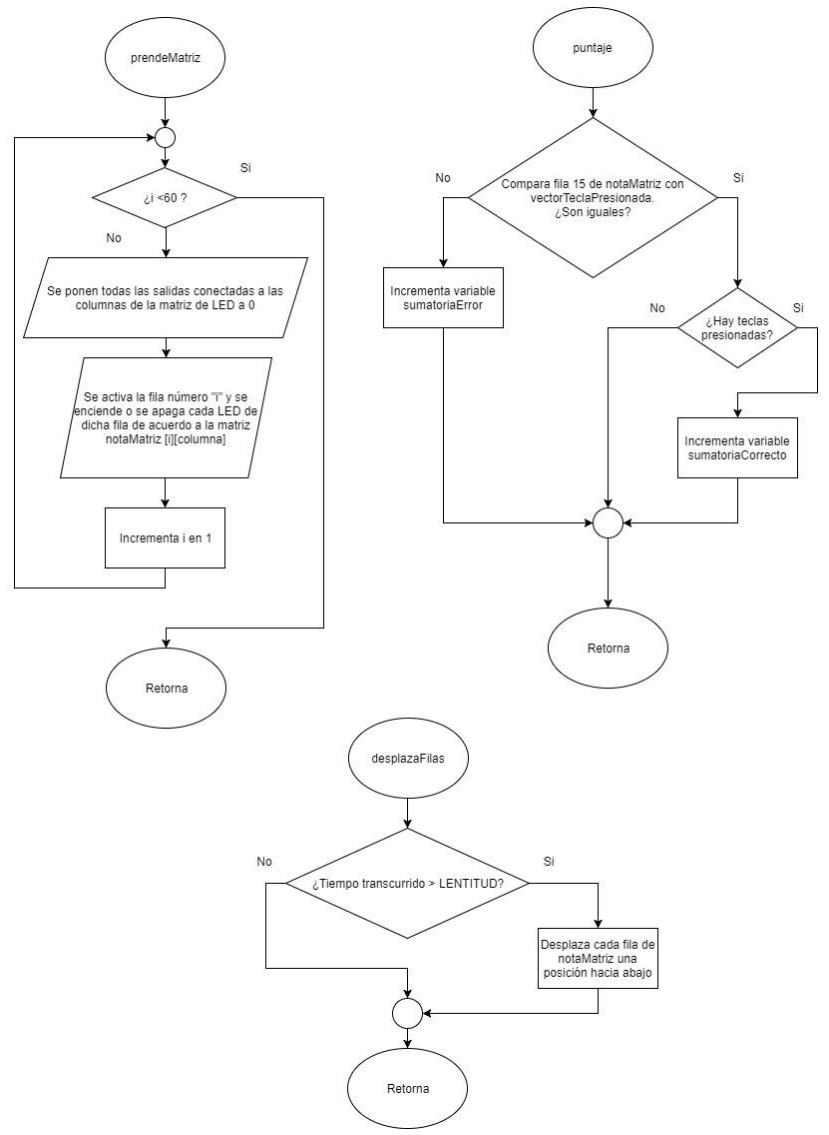
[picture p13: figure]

Ingeniería Electrónica | PianoGraph! | 41

Fig. 39 - Subrutinas

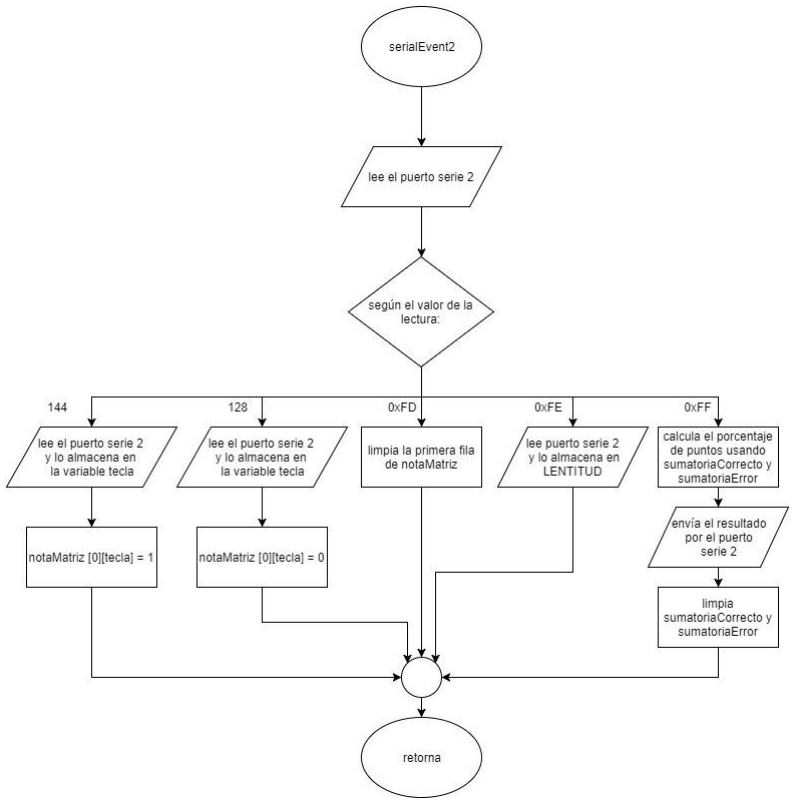
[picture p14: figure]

Ingeniería Electrónica | PianoGraph! | 42

Fig. 40 – Atención del puerto serial de parte del Bluetooth

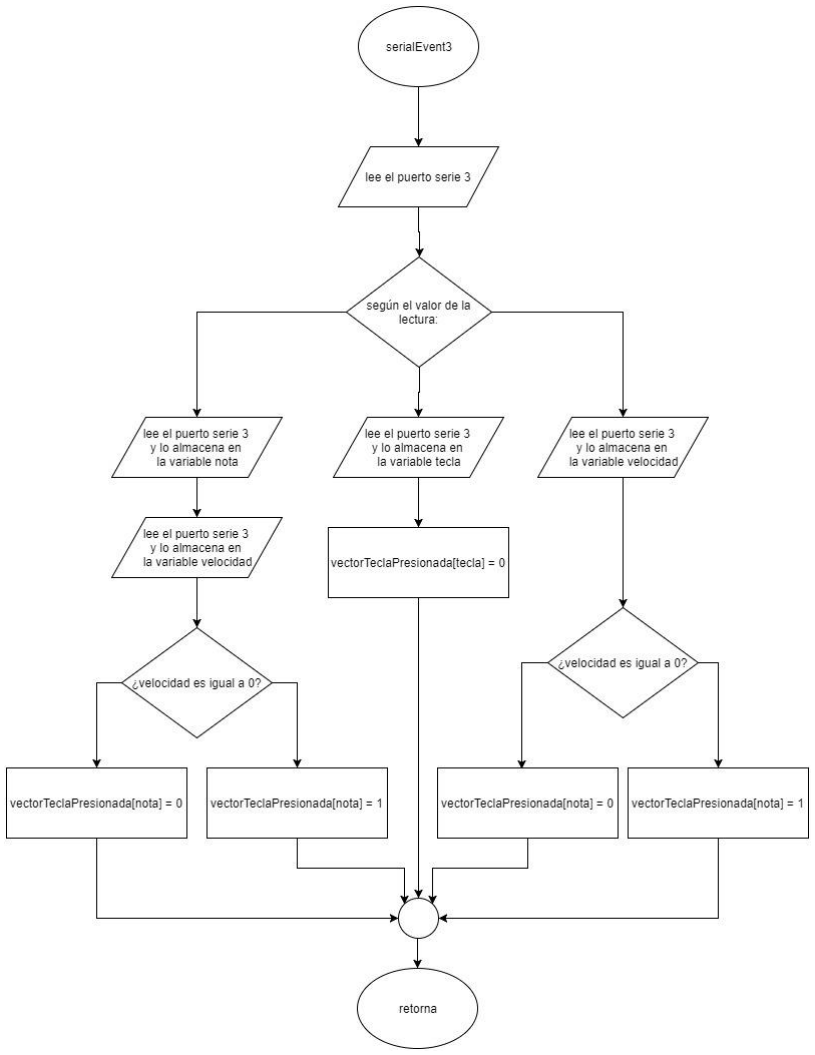
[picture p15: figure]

Ingeniería Electrónica | PianoGraph! | 43

Fig. 41 – Atención del puerto serial de parte del Teclado

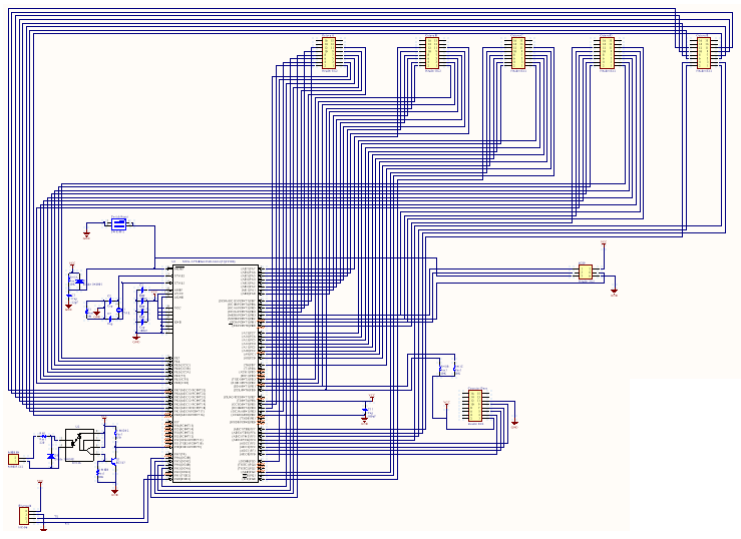
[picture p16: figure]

Ingeniería Electrónica | PianoGraph! | 44

La placa final fue diseñada utilizando el programa Altium, y el PCB se envió a

fabricar por la empresa Ernesto Mayer S.A

Esquema eléctrico:

Fig. 42 – Esquemático Placa controladora

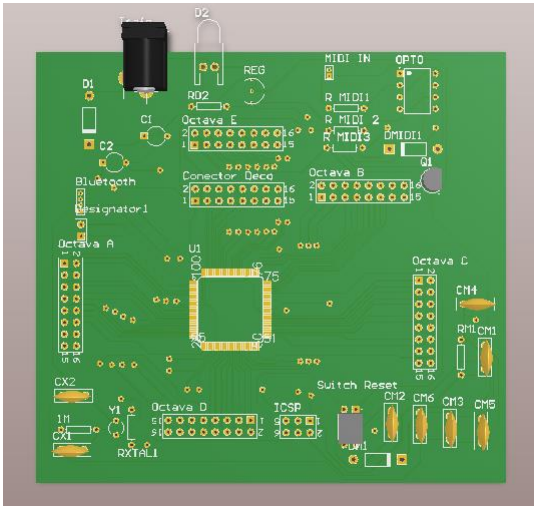
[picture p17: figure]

Ingeniería Electrónica | PianoGraph! | 45

Fig. 43 - Diseño PCB:

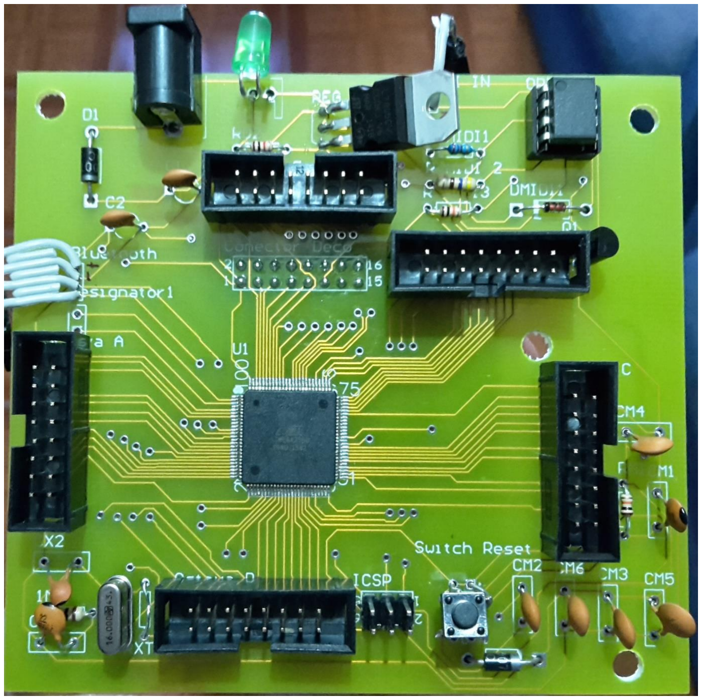
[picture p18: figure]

Ingeniería Electrónica | PianoGraph! | 46

Fig. 44 – Prototipo PCB

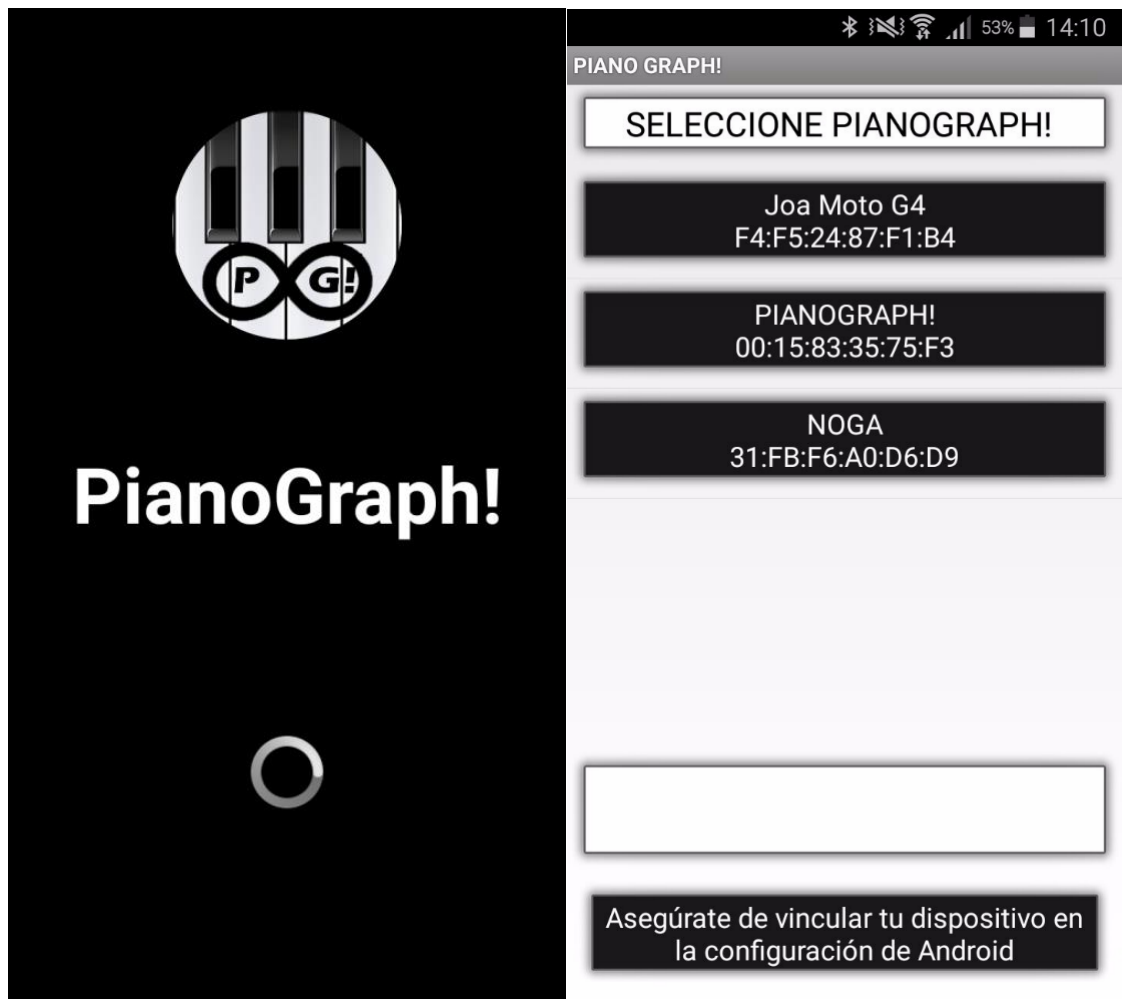
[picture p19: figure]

Ingeniería Electrónica | PianoGraph! | 47

## •Aplicación Android

La aplicación desarrollada para Android se concibió utilizando la plataforma gratuita

“Android Studio” para lo cual fue necesario incorporar una gran cantidad de

conceptos nuevos y conocimientos nunca vistos en la carrera. Dicha aplicación se

encuentra en etapa “beta” aún, pero se comporta de manera operativa, y es posible

utilizarla para manejar “PianoGraph!”.

La aplicación realiza las siguientes tareas:

1. Conexión inalámbrica con el dispositivo.

Fig. 45 – PianoGraph!

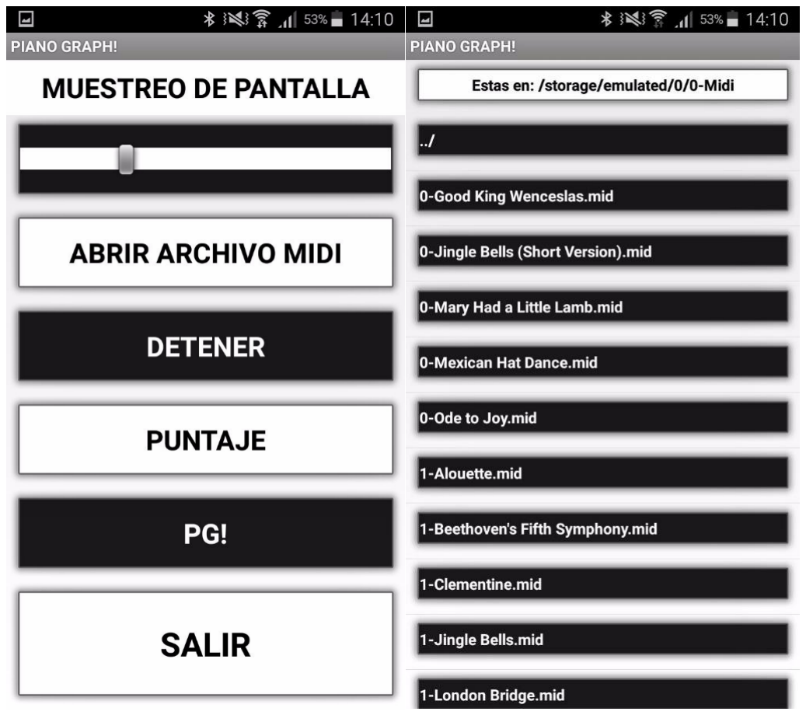
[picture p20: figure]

Ingeniería Electrónica | PianoGraph! | 48
2. Selección del archivo MIDI descargado, y comprensión del mismo

Fig. 46 y 47 – PianoGraph!

3. Envío de dicha canción a “PianoGraph!”, pudiendo controlar variables como

la velocidad de muestreo del dispositivo, y visualizar inmediatamente el

puntaje obtenido una vez finalizada la canción.

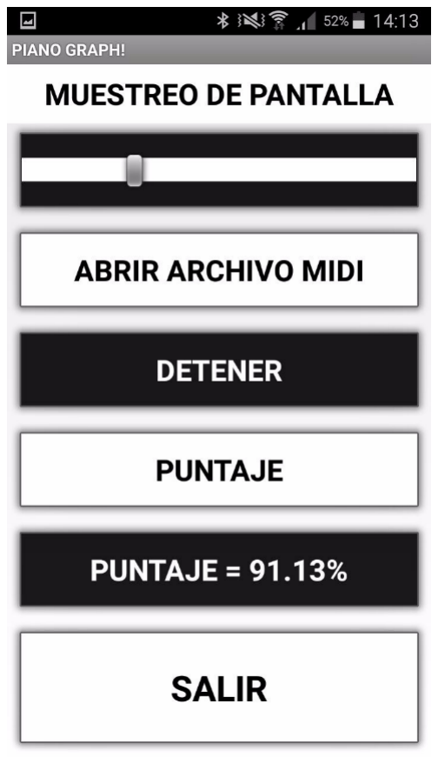
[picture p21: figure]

Ingeniería Electrónica | PianoGraph! | 49

Fig. 48 – PianoGraph!

## •Ensamblado y Carcasa

Para la realización de la carcasa, hemos utilizado piezas diseñadas por nosotros y

producidas gracias a la tecnología de impresión 3D, utilizando una impresora

“Geeetech Prusa i3”

Ingeniería Electrónica | PianoGraph! | 50

Fig. 49 – Geeetech Prusa i3

Una impresora 3D es una máquina capaz de realizar réplicas de diseños en 3D,

creando piezas o maquetas volumétricas a partir de un diseño hecho por ordenador,

descargado de internet o recogido a partir de un escáner 3D. Surgen con la idea de

convertir archivos de 2D en prototipos reales o 3D. Comúnmente se ha utilizado en

la prefabricación de piezas o componentes, en sectores como la arquitectura y

el diseño industrial. En la actualidad se está extendiendo su uso en la fabricación de

todo tipo de objetos, modelos para vaciado, piezas complicadas,

alimentos, prótesis médicas (ya que la impresión 3D permite adaptar cada pieza

fabricada a las características exactas de cada paciente), etc.

La impresión 3D en el sentido original del término se refiere a los procesos en los

que secuencialmente se acumula material en una cama o plataforma por diferentes

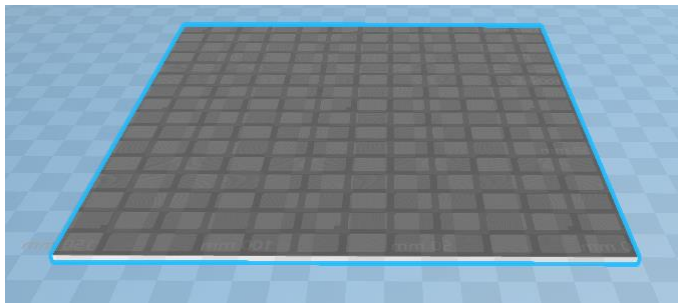
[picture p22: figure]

Ingeniería Electrónica | PianoGraph! | 51

métodos de fabricación, tales como polimerización, inyección de aporte, inyección de

aglutinante, extrusión de material, cama de polvo, laminación de metal, depósito

metálico.

Las piezas diseñadas consisten en una lámina de aproximadamente 100mm x

130mm, que se encuentra subdividida en celdas de 10x13.5mm, que corresponden

a un cobertor de un led. Teniendo entonces 192 celdas de plástico traslúcido,

cubriendo cada una un led diferente.

Fig. 50 – Cobertor de 192 ledes

Fig. 51 – Cobertor de 192 ledes

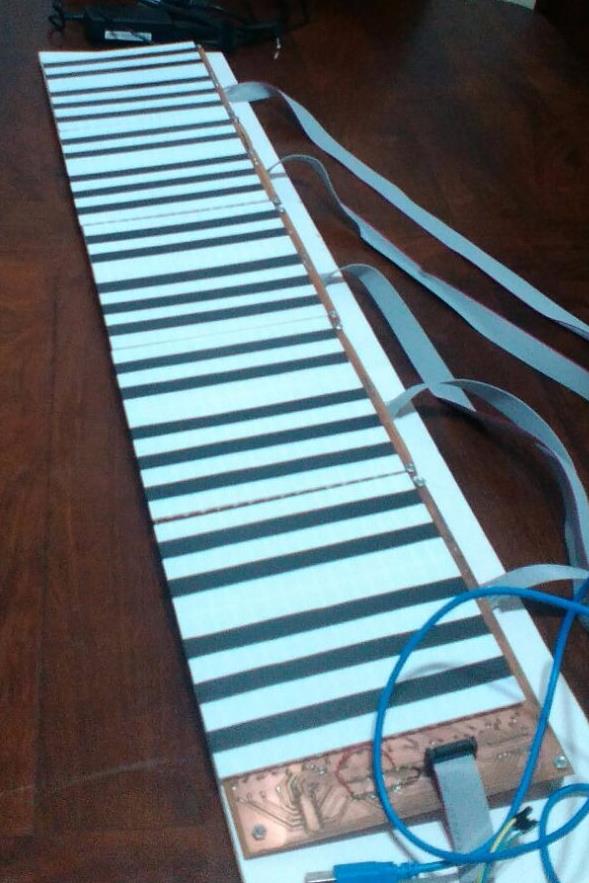
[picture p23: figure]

Ingeniería Electrónica | PianoGraph! | 52

Una vez impresas las 5 piezas correspondientes una a cada octava del dispositivo,

procedimos a diferenciar las columnas correspondientes a las notas “sostenidas” o

“bemoles” (notas identificadas con el color negro en los pianos), cubriendo éstas con

papel vinilo semitransparente de color negro. Siendo el resultado final el siguiente:

Fig. 52 – Primer montaje

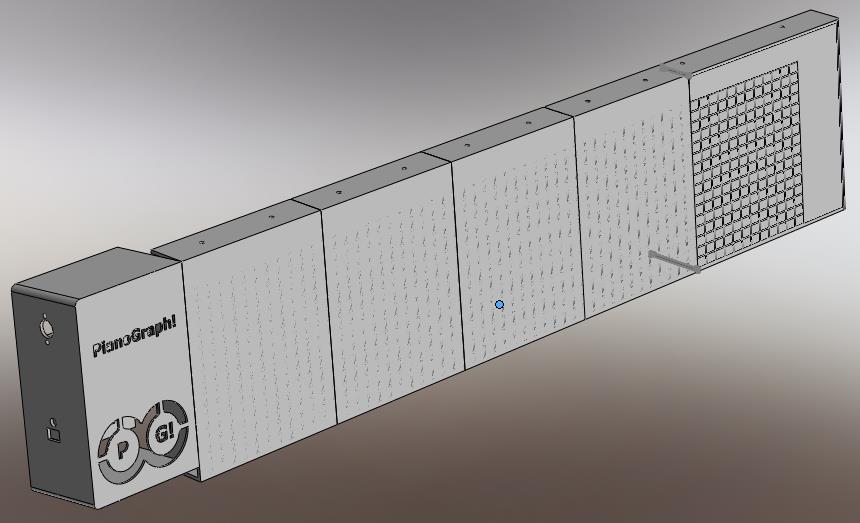
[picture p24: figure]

Ingeniería Electrónica | PianoGraph! | 53

Luego de comprobar que el dispositivo funcionaba correctamente, hemos decidido

mejorar la estética del mismo, y volver a diseñar las piezas que componen la

carcasa del mismo, además reduciendo los tiempos de ensamblaje mediante la

fabricación de piezas más fáciles de montar. Todas estas piezas fueron diseñadas

utilizando el software “SolidWorks”

Fig. 53 – Ensamblaje final

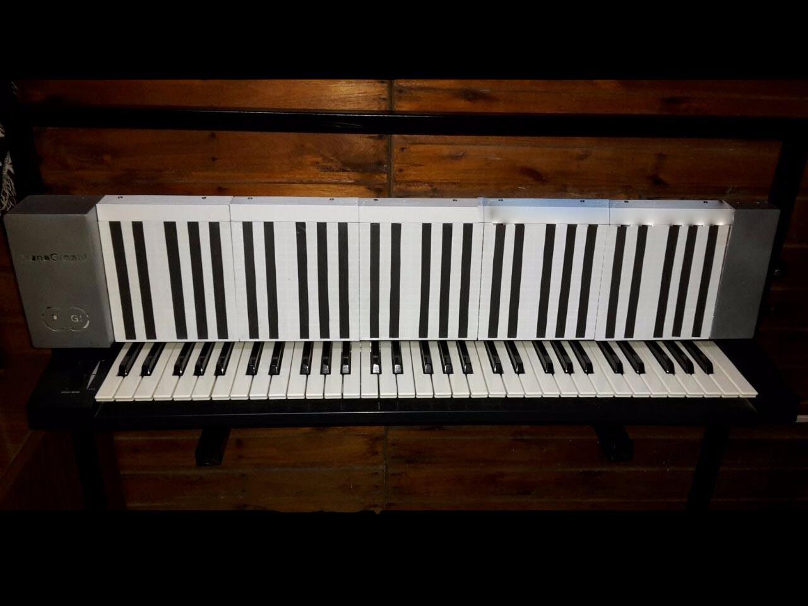
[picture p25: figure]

Ingeniería Electrónica | PianoGraph! | 54

Fig. 54 – Dispositivo listo

Ingeniería Electrónica | PianoGraph! | 55

CONCLUSIONES

Este proyecto presentó un gran desafío personal y profesional para nosotros, en el

cual debimos aplicar una amplia gama de conocimientos adquiridos durante nuestra

formación académica, y además, incorporar gran cantidad de nueva información

quizás lejos de estar relacionada con la electrónica, pero a su vez igual o aún más

necesaria, ya sean aspectos mecánicos, de diseño, económicos, de organización de

un proyecto, y demás elementos siempre presentes a la hora de encarar un

emprendimiento (algo que deberemos enfrentar a partir de ahora y a lo largo de

nuestra carrera profesional).

La concepción inicial de la idea no incluía el desarrollo de una aplicación Android

exclusiva para el dispositivo ni la obtención de un puntaje, pero gracias a la

cooperación de ambos, la investigación, la asistencia siempre disponible de parte de

la UTN, las herramientas ofrecidas por nuestros mentores a lo largo de estos casi

seis años de formación y la ayuda de compañeros, hemos conseguido superar los

primeros objetivos y avanzar para conseguir un prototipo completo del producto final

deseado.

Además, este proyecto fue realizado con gran empeño, ya que consideramos real la

posibilidad de producción y comercialización. Tenemos grandes expectativas para

comenzar su fabricación en el transcurso del año 2018. No queremos, como tantos

otros trabajos finales, que éste sea sólo una calificación más en nuestro certificado

analítico, y que sea guardado en un archivo, en el olvido.

No nos quedan más palabras que de agradecimiento para todos aquellos que nos

acompañaron en este camino.

Ingeniería Electrónica | PianoGraph! | 56

APÉNDICE

Descargas MIDI: www.8notes.com

Información útil: http://www.css-audiovisual.com/areas/guias/midi.htm

Datasheet Mega2560 : http://pdf1.alldatasheet.com/datasheet-

pdf/view/107092/ATMEL/ATMEGA2560.html (http://pdf1.alldatasheet.com/datasheet-pdf/view/107092/ATMEL/ATMEGA2560.html)

Datasheet optoacopladores:

PC817: http://pdf1.alldatasheet.com/datasheet-pdf/view/43368/SHARP/PC817.html

4N26: http://pdf1.alldatasheet.com/datasheet-pdf/view/2847/MOTOROLA/4N26.html

6N136: http://pdf1.alldatasheet.com/datasheet-pdf/view/35184/QT/6N136.html

Datasheet CD74HC4514: http://pdf1.alldatasheet.com/datasheet-

pdf/view/26940/TI/CD74HC4514.html (http://pdf1.alldatasheet.com/datasheet-pdf/view/26940/TI/CD74HC4514.html)

Datasheet ULN2803: http://pdf1.alldatasheet.com/datasheet-

pdf/view/12687/ONSEMI/ULN2803.html (http://pdf1.alldatasheet.com/datasheet-pdf/view/12687/ONSEMI/ULN2803.html)

Web Arduino (soporte y comunidad): https://www.arduino.cc/

Datasheet ledes: https://www.dled.com.ar/producto/download-

documento/?id=53&pr=280 (https://www.dled.com.ar/producto/download-documento/?id=53&pr=280)

Ingeniería Electrónica | PianoGraph! | 57

BIBLIOGRAFÍA

- Instituto Nacional de Estadística y Geografía

-Instituto de Sociología Musical de la Universidad de Viena de Música y Arte

Dramático.

- Sergi Jordà Puig, Audio digital y MIDI, Guías Monográficas Anaya Multimedia,

Madrid 1997

- The MIDI Manual, Second Edition, Libro de David Miles Huber
- El Sistema Midi, Libro de Antonio Mínguez Olivares, Antonio Pedrero González,

Fernando Garcia Moreno y Francisco J. Tabernero Gil

Ingeniería Electrónica | PianoGraph! | 58

ANEXO I

PERSISTENCIA DE LA VISIÓN

La persistencia de la visión fue un supuesto fenómeno visual descubierto por Peter

Mark Roget que demostraría como una imagen permanece en la retina humana una

décima de segundo antes de desaparecer por completo.

Según sus estudios, esto permitiría que veamos la realidad como una secuencia de

imágenes ininterrumpidas y que podamos calcular fácilmente la velocidad y dirección

de un objeto que se desplaza, si no existiese, veríamos pasar la realidad como

sucesión de imágenes independientes y estáticas.

Joseph-Antoine Ferdinand Plateau creyó descubrir que nuestro ojo ve con una

cadencia de diez imágenes por segundo. En virtud de dicho fenómeno, las imágenes

se superponen en la retina y el cerebro las "enlaza" como una sola imagen visual,

móvil y continua.

Se supuso que el cine aprovechaba este efecto y provoca ese "enlace" proyectando

a más de 10 imágenes por segundo (generalmente 24), lo que genera en nuestro

cerebro la ilusión de movimiento (la televisión se da a 29,97 fotogramas por

segundo, y 25 en Europa).

Ley de Ferry-Porter

Hay un amplio margen de frecuencias desde la absoluta evidencia de parpadeo

hasta la sensación de continuidad. Este fenómeno se conoce con el término inglés

flicker. La frecuencia en la que las imágenes se funden y desaparece el parpadeo lo

llamamos frecuencia crítica de flicker y, como ya hemos apuntado, depende del nivel

de iluminación de la pantalla. Es una dependencia de tipo logarítmico y se conoce

como ley de Ferry-Porter:

fIlindar = 37 + 12,6 log(B)

B = nivel de brillo de la pantalla medido en foot-lambert.

Ingeniería Electrónica | PianoGraph! | 59

Se considera que la frecuencia umbral o crítica es del orden de 40 Hz (algo más baja

en un cine por ejemplo donde las condiciones de iluminación se adecuan al

visionado). Sin embargo, esta frecuencia podrá variar entre los 60 Hz (fuerte

iluminación diurna) hasta 4 Hz (iluminación nocturna y visión fotópica). Esto se

explica gracias a la naturaleza de los conos y bastones. Los primeros (conos) captan

las imágenes en entornos de alta iluminación y lo hacen con una respuesta bastante

elevada. Por el contrario, los bastones son mucho más sensibles, de ahí que se

encarguen de captar en entornos de iluminación precaria. Ahora bien, necesitan

mucho más tiempo para excitarse y volver a la situación inicial de reposo (hasta 0,25

segundos).

Fig. 55

Ingeniería Electrónica | PianoGraph! | 60

### Anexo II.”D”

### Resolución CD 605/2015

### Declaración Jurada de Originalidad del

### Proyecto Final

Los autores del Proyecto Final titulado: Sistema de aprendizaje virtual para piano,

Declaramos bajo Juramento:

1. Que el Proyecto Final no ha sido plagiado ni total ni parcialmente, para la cual se han respetado las normas internacionales de citas y referencias para las fuentes consultadas.
2. Que el Proyecto Final presentado no atenta contra derechos de terceros.
3. Que el Proyecto Final no ha sido publicado ni presentado anteriormente para obtener a l g ú n grado académico previo o título profesional.
4. Que los datos presentados en los resultados son reales, no han sido falsificados, ni duplicados,ni copiados.
5. Que se adjuntará al presente un acuerdo formal de la parte involucrada, si el proyecto tuviese información relacionada sobre una empresa o institución.

Por lo expuesto, mediante la presente asumo frente LA UNIVERSIDAD cualquier responsabilidad

que pudiera derivarse por la autoría, originalidad y veracidad del contenido del Proyecto

Final,así como por los derechos sobre la obra y/o invención presentada. En consecuencia, me hago

responsable frente a LA UNIVERSIDAD y frente a terceros, de cualquier daño que pudiera

ocasionar a LA UNIVERSIDAD o a terceros, por el incumplimiento de lo declarado o que

pudiera encontrar causa en El Proyecto Final presentado, asumiendo todas las cargas que

pudieran derivarse de ello.

De identificarse fraude, piratería, plagio, falsificación o que el Proyecto Final haya sido publicado

anteriormente; asumo las consecuencias y sanciones que de mi acción se deriven,

sometiéndome a la normatividad vigente de la UTN.

Ingeniería Electrónica | PianoGraph! | 61

Lugar y fecha: San Francisco, Córdoba, 27 de noviembre de 2017.

Integrantes del grupo:

Nombre: Daniele, Fernando Ezequiel |

Firma.: ___________________

Nombre: Velazquez, Gonzalo Martín |

Firma.:___________________

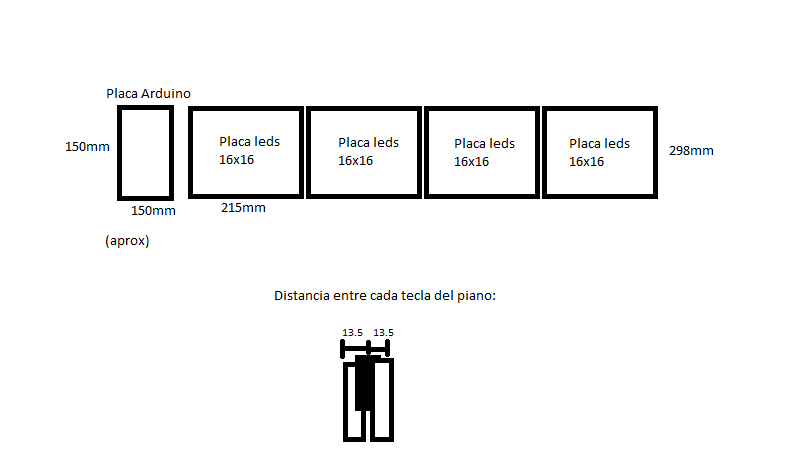
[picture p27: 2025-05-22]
Info/Dimensiones.png

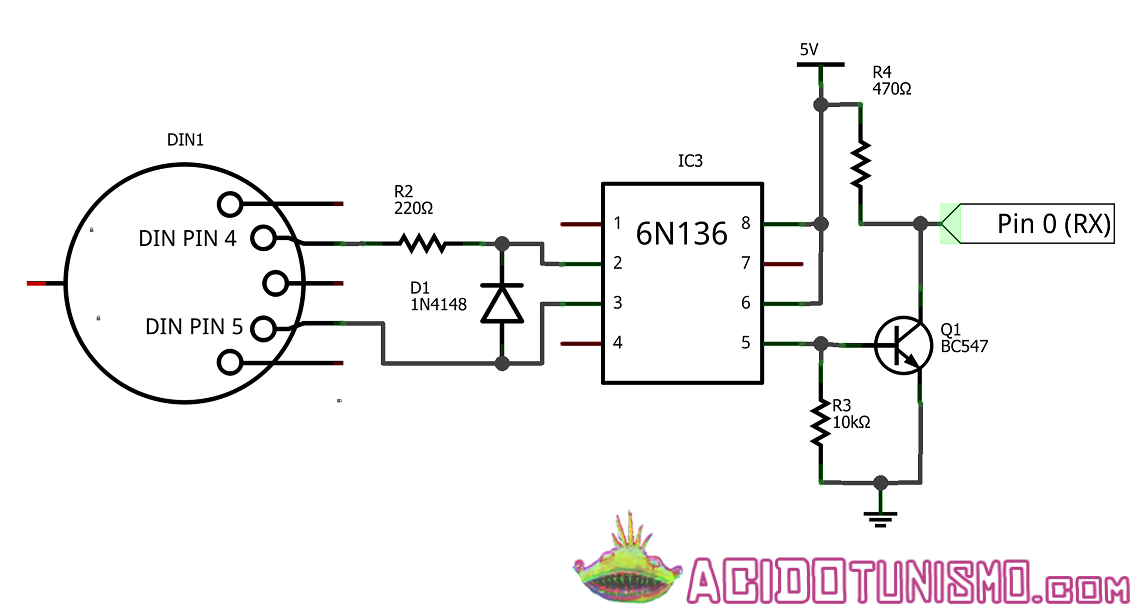
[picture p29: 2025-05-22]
Arduino/midi_in-arduino-uno-low-gain-opto_schem21.png

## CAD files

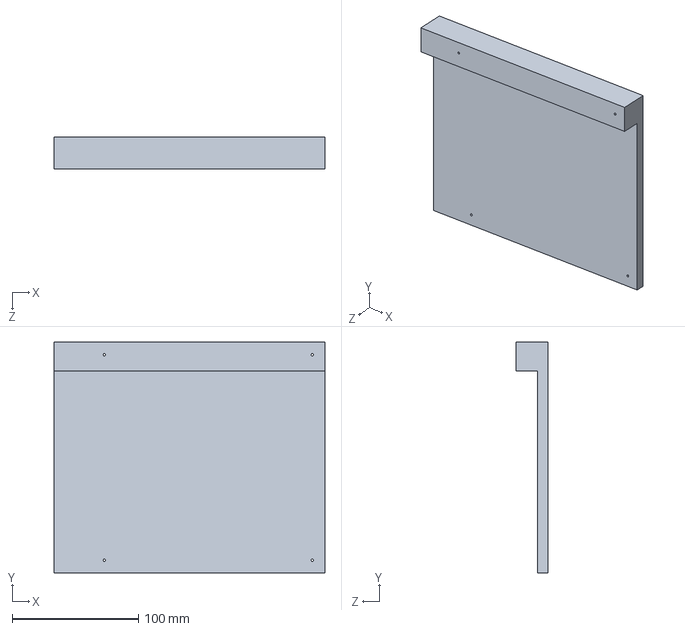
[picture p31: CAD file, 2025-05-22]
Solid/Representacion placa leds 16x16.SLDPRT
215.0 x 183.0 x 25.0 mm

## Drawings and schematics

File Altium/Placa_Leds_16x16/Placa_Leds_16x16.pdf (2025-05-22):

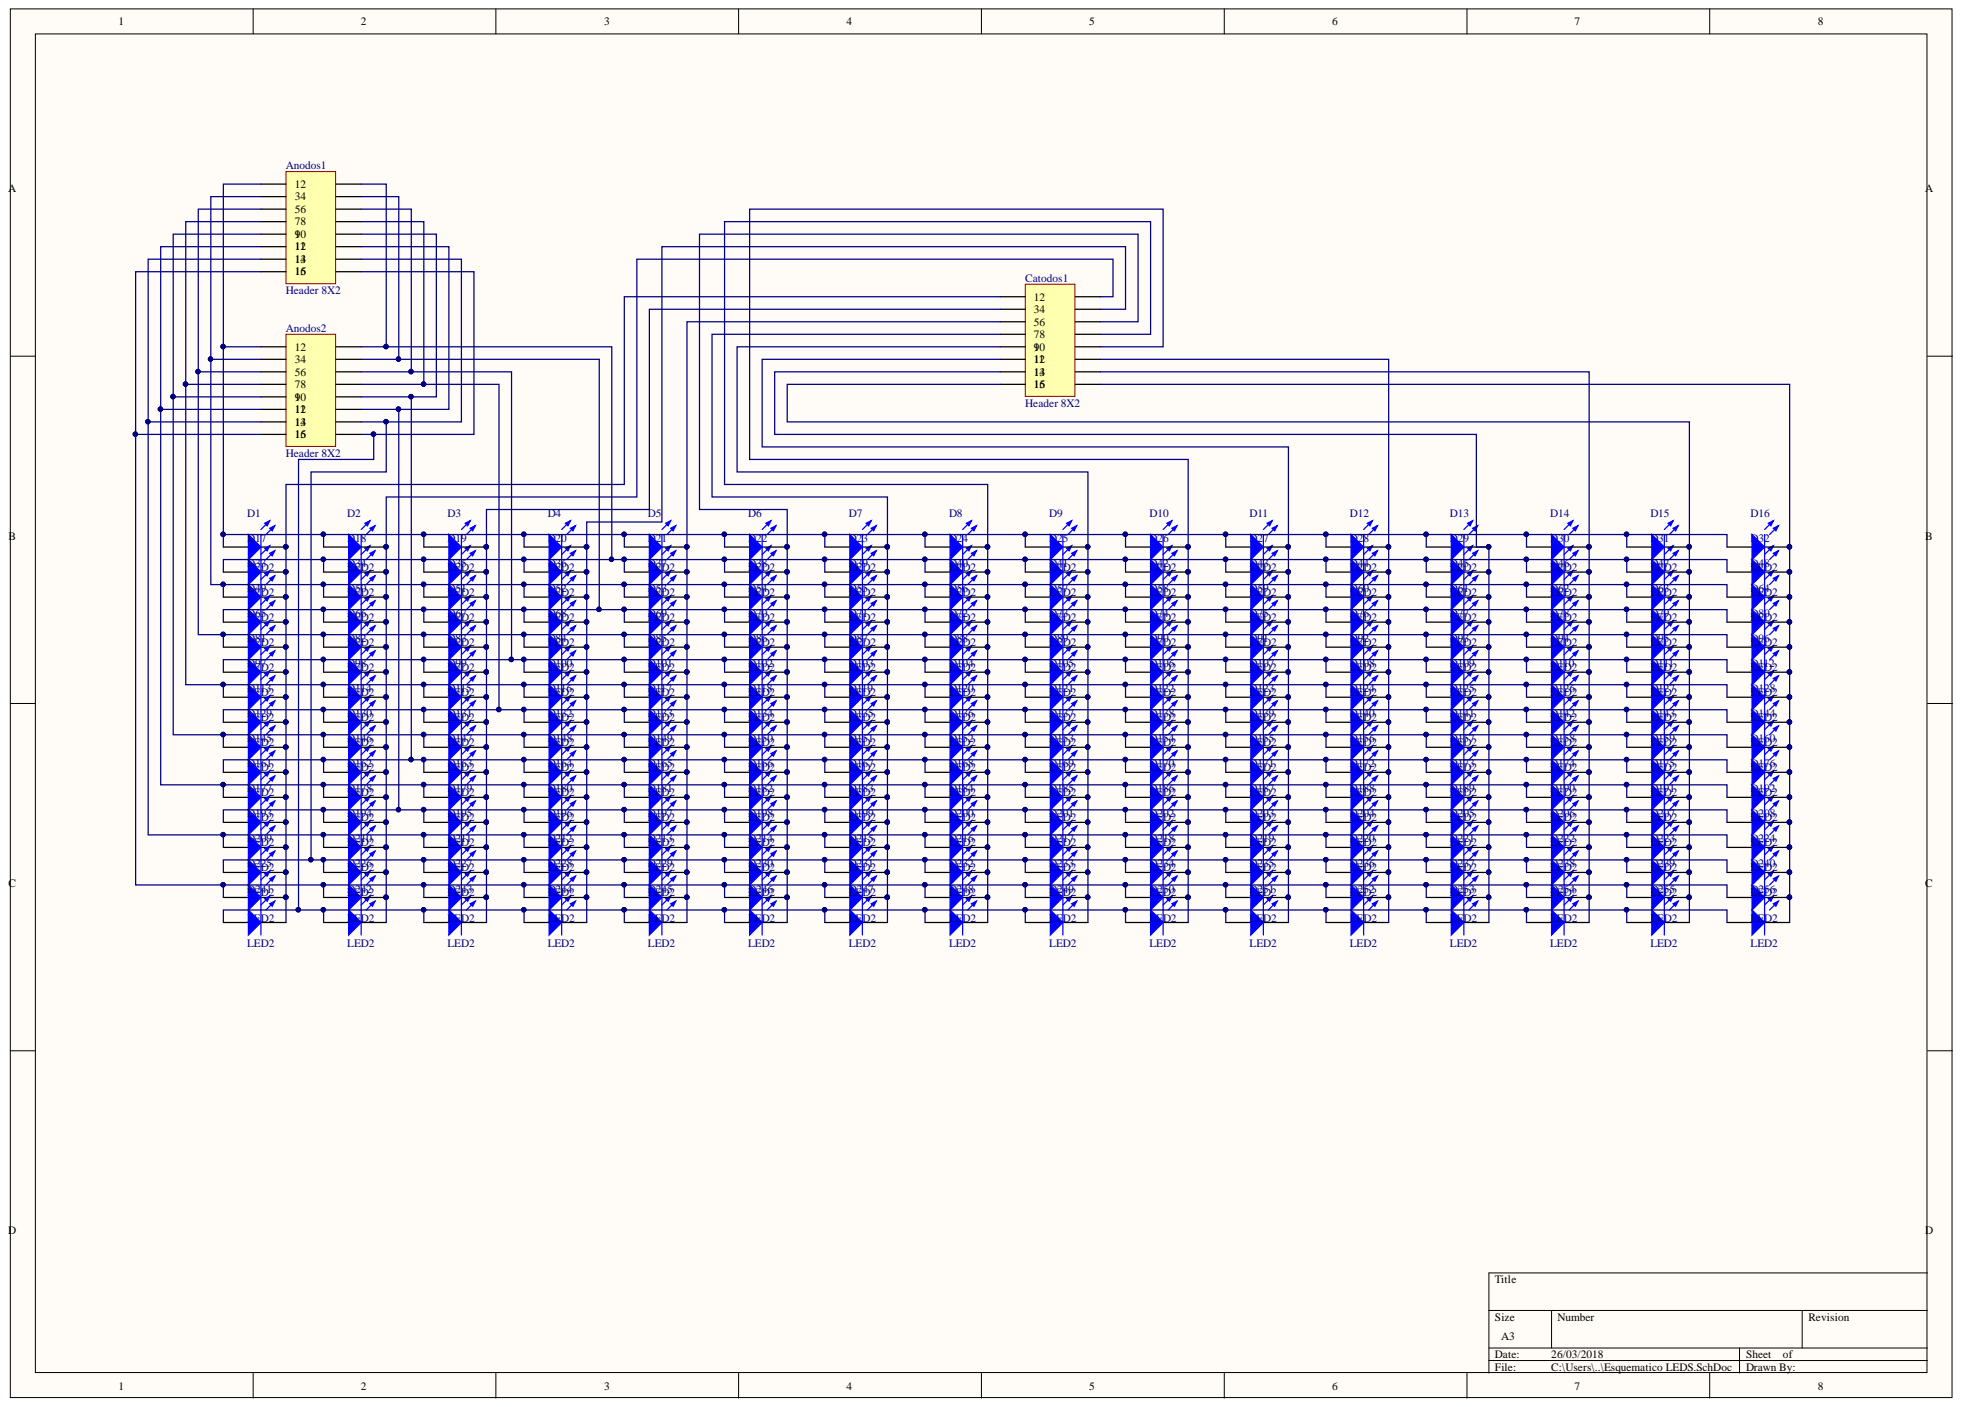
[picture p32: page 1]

LED2 D33 | | LED2 | D35 LED2 | LED2 | LED2 | LED2 | LED2 | LED2 | LED2 | LED2 | LED2 | LED2 | LED2 | LED2 | LED2

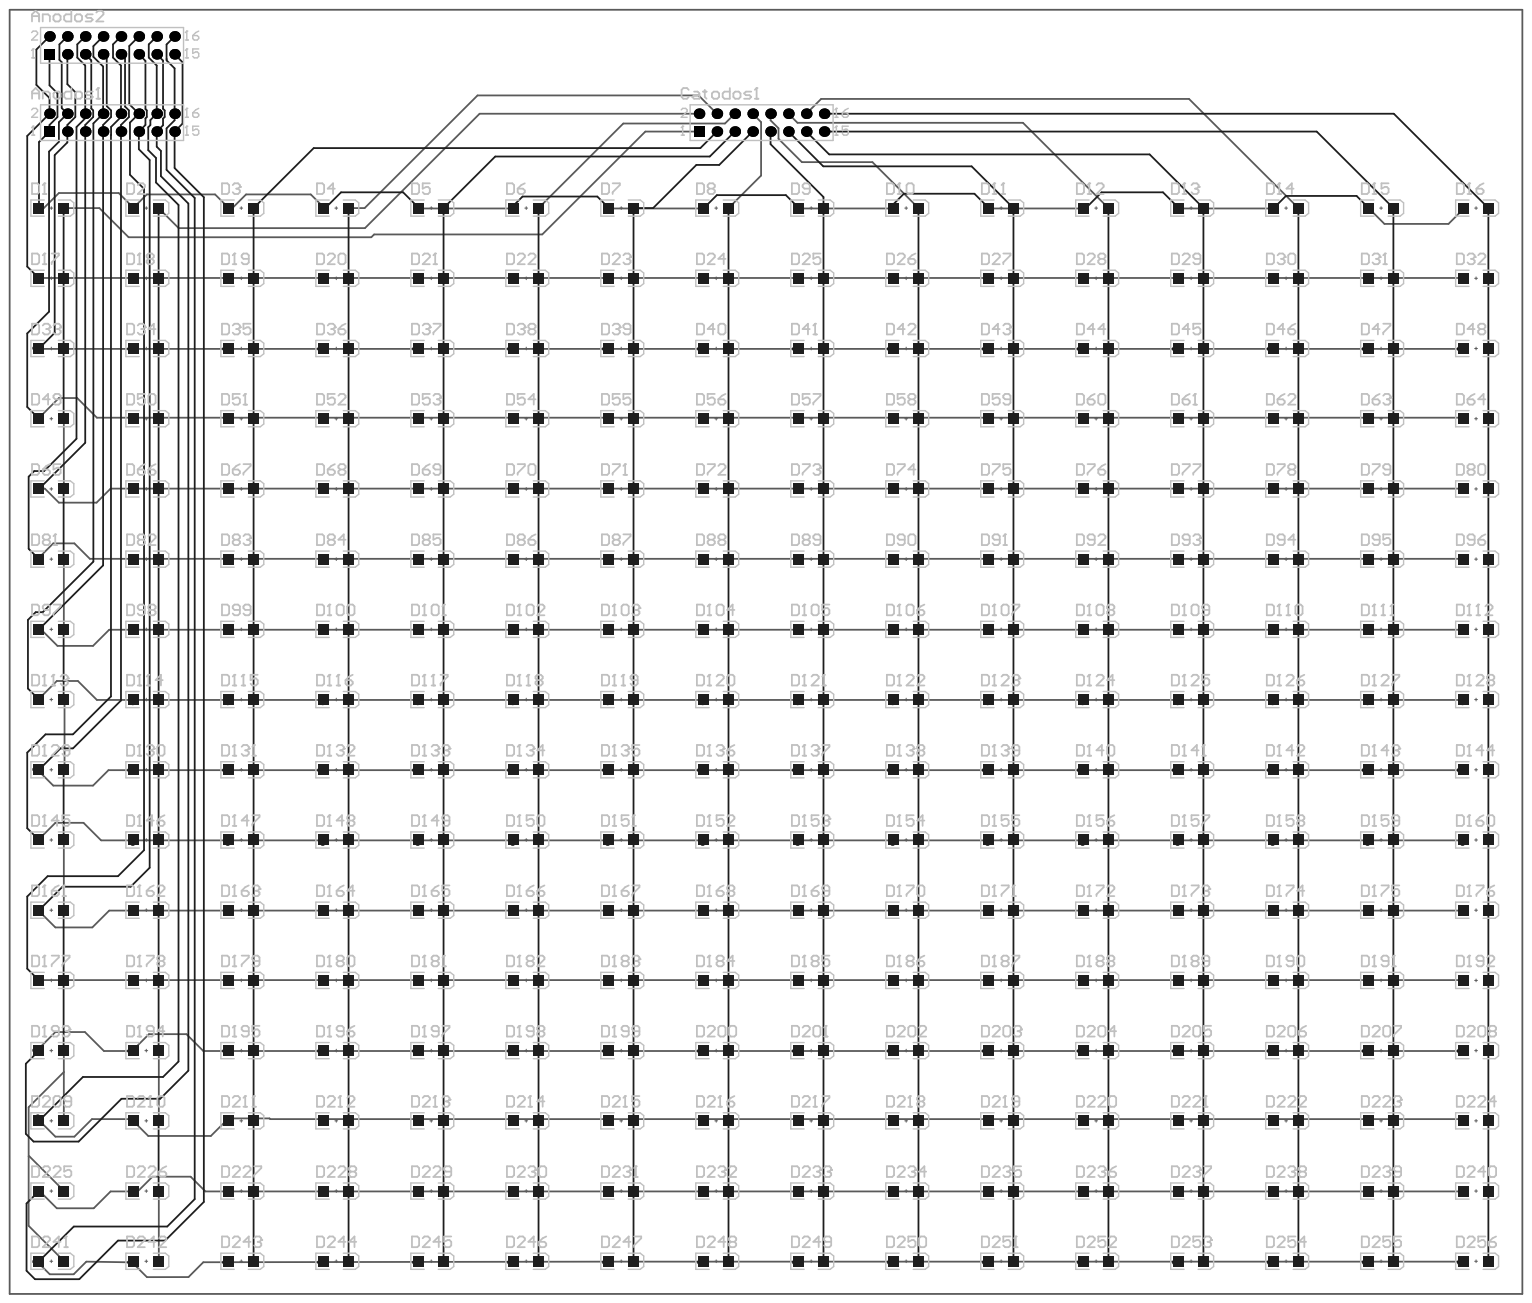
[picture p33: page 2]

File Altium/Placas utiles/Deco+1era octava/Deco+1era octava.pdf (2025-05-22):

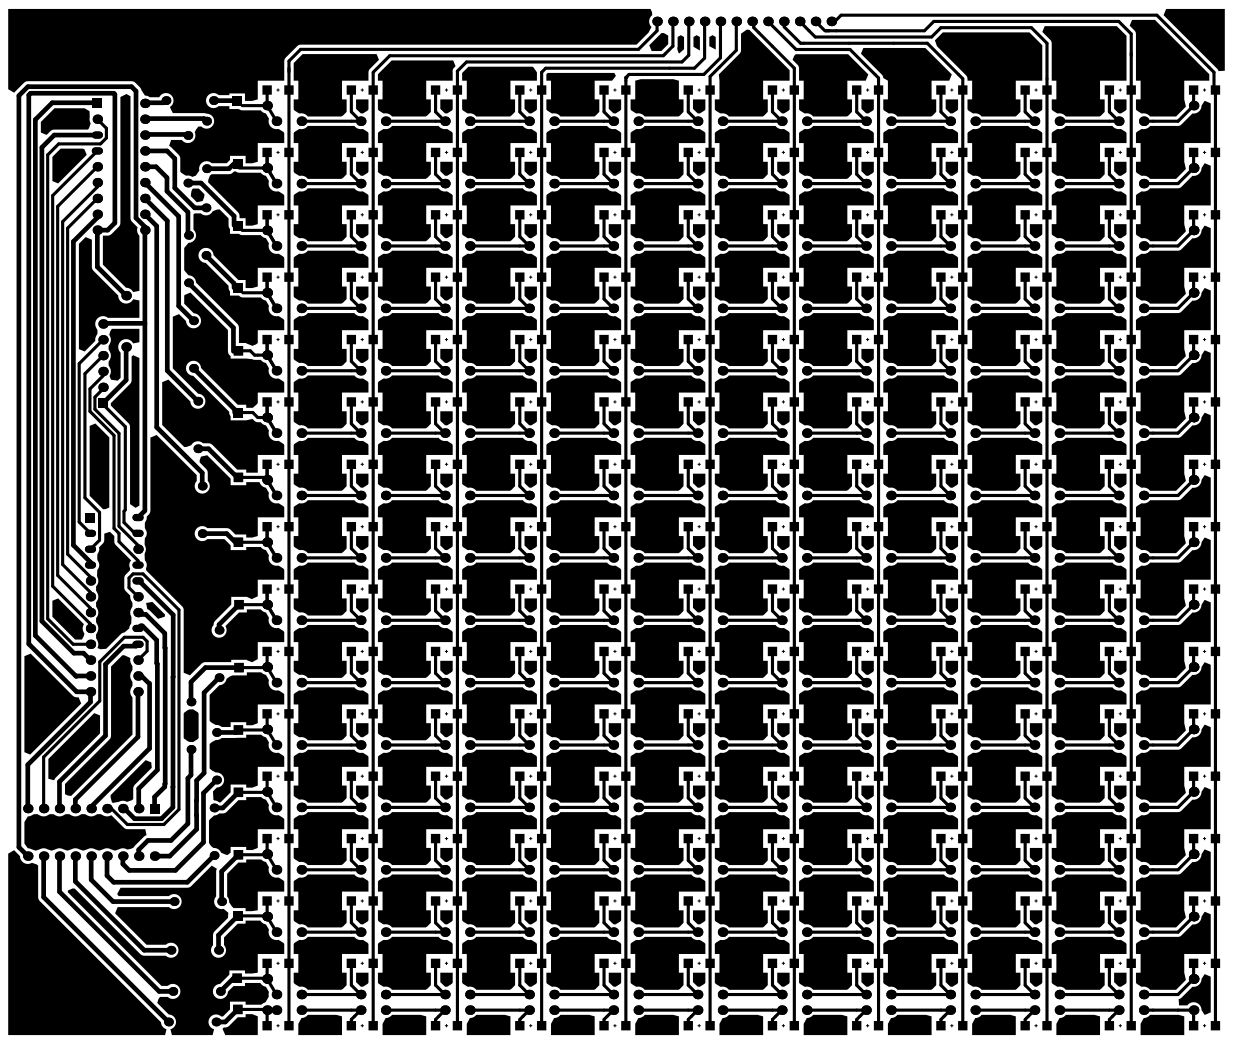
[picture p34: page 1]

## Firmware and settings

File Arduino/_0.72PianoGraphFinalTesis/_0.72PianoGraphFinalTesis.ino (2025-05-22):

//*********************** DEFINES, VARIABLES GLOBALES ************************************************
#define canalA 0
#define canalB 1
#define canalC 2
#define canalD 3
#define canalE 4
#define canalF 5
#define canalG 6
#define canalH 7
#define canalI 8
#define canalJ 9
#define canalK 10
#define canalL 11
#define canalM 12
#define canalN 13
#define canalO 14
#define canalP 15
#define resolucionPuntaje 10

byte LENTITUD=50;
byte nota=0;
byte velocidad=0;
byte lectura=0;
boolean banderaT0=1,posibleNotaOff=0;
boolean ledsApagados=0;
int tecla=0;
int teclaInicial=36;
int teclaFinal=95;
unsigned long T0,T1;
boolean notaMatriz[17][60]={0};
boolean vectorNota[60]={0}; //PARA CUANDO HAY SUCESIÓN RAPIDA DE NOTAS ON-OFF
boolean vectorNotaCorta[60]={0}; //para cuando hay una nota corta que no llega a pasar a la primera fila
boolean vectorTeclaPresionada[60]={0};
float tiempoCorrecto=0,tiempoError=0,sumatoriaCorrecto=0,sumatoriaError=0;
float tiempoSumaPrograma=0;
boolean banderaCorrecto=0,banderaError=0;
float porcentajeCorrecto=0;
boolean distinto=1;


//*********************** SETUP ************************************************

void setup()
  {
  for(int i=2;i<14;i++)
    {  
    pinMode(i,OUTPUT);
    }
  
  for(int i=18;i<70;i++)
    {  
    pinMode(i,OUTPUT);
    }
  Serial2.begin(115200);
  Serial3.begin(31250);
  }

//*********************** LOOP ************************************************

void loop() 
  {
  if(banderaT0==1)
    {
    T0=millis();
    T1=T0;
    banderaT0=0;    
    }
    
    prendeMatriz();

      
    
    desplazaFilas();
 
  }

//*********************** FUNCIONES ************************************************
 
void prendeMatriz()
  {
  for(int a=0;a<16;a++)
    {  
    for(int b=2;b<14;b++)
      {
      digitalWrite(b,0);
      }
    for(int b=18;b<54;b++)
     {
     digitalWrite(b,0);
     }
     for(int b=58;b<70;b++)
     {
     digitalWrite(b,0);
     }
     
    PORTF=a;
    
    for(int b=2;b<14;b++)
      {
      digitalWrite(b,notaMatriz[a][b-2]);
      }
    for(int b=18;b<54;b++)
      {
      digitalWrite(b,notaMatriz[a][b-6]);
      }
    for(int b=58;b<70;b++)
      {
      digitalWrite(b,notaMatriz[a][b-10]);
      }     
    }
  }

void desplazaFilas()
  {
  if (millis()-T0 > LENTITUD)
      {
        puntaje();

       
     
      for(int a=16;a>0;a=a-1)
        {
        for(int k=0;k<60;k++)
          {
           notaMatriz[a][k]=notaMatriz[(a-1)][k];
           }
        }


       for(int m=0;m<60;m++)
        {
          if(vectorNotaCorta[m]==1)
            {
             notaMatriz[0][m]=0; //una vez que nos aseguramos que el LED prendido ya se desplazó, mostramos el nota OFF
              vectorNotaCorta[m]=0;
            } 
        }


//REVISAR ESTO!! PUEDE QUE QUEDE UNA COLUMNA SIEMPRE PRENDIDA!!
      
      for(int m=0;m<60;m++)
        {
          if(vectorNota[m]==1)
            {
              notaMatriz[0][m]=1; //una vez que nos aseguramos que el LED apagado ya se desplazó, mostramos el nota ON
              vectorNota[m]=0;
            } 
        } 

        T0=millis();
      }
   
  }
  

//---------------Aplicación----------------------

void serialEvent2() 
  {
    
    lectura= Serial2.read();
    
    switch (lectura)
      {
      
      case (128+canalA):
                    comandoOff(); // hay notaOff
                    break;
      case (144+canalA):
                    comandoOn(); //hay notaOn
                    break;                    
      case (128+canalB):
                    comandoOff(); // hay notaOff
                    break;
      case (144+canalB):
                    comandoOn();
                    break;
      case (128+canalC):
                    comandoOff(); // hay notaOff
                    break;
      case (144+canalC):
                    comandoOn(); //hay notaOn
                    break;  
      case (128+canalD):
                    comandoOff(); // hay notaOff
                    break;
      case (144+canalD):
                    comandoOn(); //hay notaOn
                    break;  
      case (128+canalE):
                    comandoOff(); // hay notaOff
                    break;
      case (144+canalE):
                    comandoOn(); //hay notaOn
                    break;  
      case (128+canalF):
                    comandoOff(); // hay notaOff
                    break;
      case (144+canalF):
                    comandoOn(); //hay notaOn
                    break;  
      case (128+canalG):
                    comandoOff(); // hay notaOff
                    break;
      case (144+canalG):
                    comandoOn(); //hay notaOn
                    break;  
      case (128+canalH):
                    comandoOff(); // hay notaOff
                    break;
      case (144+canalH):
                    comandoOn(); //hay notaOn
                    break;  
     case (128+canalI):
                    comandoOff(); // hay notaOff
                    break;
      case (144+canalI):
                    comandoOn(); //hay notaOn
                    break;  
      case (128+canalJ):
                    comandoOff(); // hay notaOff
                    break;
      case (144+canalJ):
                    comandoOn(); //hay notaOn
                    break;  
      case (128+canalK):
                    comandoOff(); // hay notaOff
                    break;
      case (144+canalK):
                    comandoOn(); //hay notaOn
                    break;  
    case (128+canalL):
                    comandoOff(); // hay notaOff
                    break;
      case (144+canalL):
                    comandoOn(); //hay notaOn
                    break;  
      case (128+canalM):
                    comandoOff(); // hay notaOff
                    break;
      case (144+canalM):
                    comandoOn(); //hay notaOn
                    break;  
     case (128+canalN):
                    comandoOff(); // hay notaOff
                    break;
      case (144+canalN):
                    comandoOn(); //hay notaOn
                    break;  
      case (128+canalO):
                    comandoOff(); // hay notaOff
                    break;
      case (144+canalO):
                    comandoOn(); //hay notaOn
                    break;  
     case (128+canalP):
                    comandoOff(); // hay notaOff
                    break;
      case (144+canalP):
                    comandoOn(); //hay notaOn
                    break;
      case 0xFD:{
                for(int h=0;h<60;h++)
                  {
                    notaMatriz[0][h]=0;
                  }
                break;
                }              
      case 0xFE:{
                LENTITUD=Serial2.read();
                break;
                }
      case 0xFF:{      
                tiempoSumaPrograma=sumatoriaCorrecto+sumatoriaError;
                porcentajeCorrecto=100*sumatoriaCorrecto/tiempoSumaPrograma;
                Serial2.print(porcentajeCorrecto);
                Serial2.print('~'); //con esto damos a conocer la finalización del String de datos
                Serial2.println();
                delay(10);
                sumatoriaCorrecto=0;
                sumatoriaError=0;  
                break;
                }
      //default:
                    /*while(Serial2.available()==0)
                    {}
                    if(Serial2.read()==0)   //es velocidad 0
                      {
                      rutinaNotaOff(lectura);
                      }
                    else
                      {
                      rutinaNotaOn(lectura);  
                      }*/
      }
 }

void comandoOff()
  {
  while(Serial2.available()==0)
  {}
  rutinaNotaOff(Serial2.read());
  //while(Serial2.available()==0)
  //{}
  //velocidad=Serial2.read();
  }

void comandoOn()
{
  while(Serial2.available()==0)
  {}
  nota=Serial2.read();
  rutinaNotaOn(nota);
  /*while(Serial2.available()==0)
  {}
  velocidad=Serial2.read();
  if(velocidad==0)  //si w==1 es porque hay una posible nota off
    {
     rutinaNotaOff(nota);
     }
  else
    {
    rutinaNotaOn(nota);   
    }*/
    
}

void rutinaNotaOff (byte tono)
  {
  if(tono<=teclaFinal)
    {
     if(tono>=teclaInicial)
        {
          tecla=tono-teclaInicial;
          vectorNota[tecla]=0;
          notaMatriz[0][tecla]=0;
          if(notaMatriz[1][tecla]==0) //si esto sucede es porque hubo nota corta
            {
              notaMatriz[0][tecla]=1;
              vectorNotaCorta[tecla]=1;
            }
        }
    }
  }

 void rutinaNotaOn (byte tono)
 {

   if(tono<=teclaFinal)
    {
      if(tono>=teclaInicial)
        {
          tecla=tono-teclaInicial;
          if(notaMatriz[1][tecla]==1)
            {
              vectorNota[tecla]=1;  //si esto sucede, es porque hay una secuencia nota ON-OFF-ON muy rápida, entonces no prendemos el LED
            }
          else
            {
             notaMatriz[0][tecla]=1;
             
            }
          
        }
    } 
 }


//------------------------Piano-------------------------

void serialEvent3() 
  {
    lectura= Serial3.read();
    
    switch (lectura)
      {
      
      case (128+canalA):
                    comando1Off(); // hay notaOff
                    break;
      case (144+canalA):
                    comando1On(); //hay notaOn
                    break;               
      case (128+canalB):
                    comando1Off(); // hay notaOff
                    break;
      case (144+canalB):
                    comando1On();
                    break;
      case (128+canalC):
                    comando1Off(); // hay notaOff
                    break;
      case (144+canalC):
                    comando1On(); //hay notaOn
                    break;  
      case (128+canalD):
                    comando1Off(); // hay notaOff
                    break;
      case (144+canalD):
                    comando1On(); //hay notaOn
                    break;  
      case (128+canalE):
                    comando1Off(); // hay notaOff
                    break;
      case (144+canalE):
                    comando1On(); //hay notaOn
                    break;  
      case (128+canalF):
                    comando1Off(); // hay notaOff
                    break;
      case (144+canalF):
                    comando1On(); //hay notaOn
                    break;  
      case (128+canalG):
                    comando1Off(); // hay notaOff
                    break;
      case (144+canalG):
                    comando1On(); //hay notaOn
                    break;  
      case (128+canalH):
                    comando1Off(); // hay notaOff
                    break;
      case (144+canalH):
                    comando1On(); //hay notaOn
                    break;  
     case (128+canalI):
                    comando1Off(); // hay notaOff
                    break;
      case (144+canalI):
                    comando1On(); //hay notaOn
                    break;  
      case (128+canalJ):
                    comando1Off(); // hay notaOff
                    break;
      case (144+canalJ):
                    comando1On(); //hay notaOn
                    break;  
      case (128+canalK):
                    comando1Off(); // hay notaOff
                    break;
      case (144+canalK):
                    comando1On(); //hay notaOn
                    break;  
    case (128+canalL):
                    comando1Off(); // hay notaOff
                    break;
      case (144+canalL):
                    comando1On(); //hay notaOn
                    break;  
      case (128+canalM):
                    comando1Off(); // hay notaOff
                    break;
      case (144+canalM):
                    comando1On(); //hay notaOn
                    break;  
     case (128+canalN):
                    comando1Off(); // hay notaOff
                    break;
      case (144+canalN):
                    comando1On(); //hay notaOn
                    break;  
      case (128+canalO):
                    comando1Off(); // hay notaOff
                    break;
      case (144+canalO):
                    comando1On(); //hay notaOn
                    break;  
     case (128+canalP):
                    comando1Off(); // hay notaOff
                    break;
      case (144+canalP):
                    comando1On(); //hay notaOn
                    break;
      default:
                    while(Serial3.available()==0)
                    {}
                    if(Serial3.read()==0)   //es velocidad 0
                      {
                      comparacionOff(lectura);
                      }
                    else
                      {
                      comparacionOn(lectura);  
                      }             
  
      }
    }

void comando1Off()
  {
  while(Serial3.available()==0)
  {}
  comparacionOff(Serial3.read());
/*  while(Serial3.available()==0)
 {}
  velocidad=Serial3.read();
  */
  }

void comando1On()
{
  while(Serial3.available()==0)
  {}
  nota=Serial3.read();
  while(Serial3.available()==0)
  {}
  velocidad=Serial3.read();
  if(velocidad==0) 
    {
     comparacionOff(nota);
     }
  else
    {
    comparacionOn(nota);
    }  
}

void comparacionOn(byte temp)
  {
    if(temp<=teclaFinal)
    {
      if(temp>=teclaInicial)
        {
        tecla=temp-teclaInicial;
        vectorTeclaPresionada[tecla]=1;
        if((notaMatriz[14][tecla]||notaMatriz[15][tecla]||notaMatriz[16][tecla])==1)
          {
            sumatoriaCorrecto++;
          }
        else
          {
            sumatoriaError=sumatoriaError+1;  
          }
        }
    }
   
  }

void comparacionOff(byte temp)
  {
    if(temp<=teclaFinal)
    {
      if(temp>=teclaInicial)
        {
        tecla=temp-teclaInicial;
        vectorTeclaPresionada[tecla]=0;
        }
    }
   
  }

//--------------------------Puntaje---------------------------------------
void puntaje()  //tiempoCorrecto suma solomante cuando cuando hay notas presionadas y coinciden con lo mostrado en pantalla
                //si no se presiona ninguna tecla y la pantalla tampoco muestra ninguna nota(de la ultima fila), se detiene la suma del tiempoCorrecto o del tiempoError
                //siempre y cuando exista alguna de sus respectivas banderas activadas
                //siempre que haya una discrepancia entre las teclas presionadas y lo mostrado en pantalla, comienza a correr el tiempoError y se detiene el tiempoCorrecto
                //esto incluye el momomento en el cual se esta presionando una tecla y en la pantalla está todo apagado
    {   
    for(int i=0;i<60;i++)
      {
        if((notaMatriz[15][i]==vectorTeclaPresionada[i])||(notaMatriz[16][i]==vectorTeclaPresionada[i])||(notaMatriz[14][i]==vectorTeclaPresionada[i]))
          {
            distinto=0;
          }
        else
          {
            distinto=1;
            i=60;  
          }
      }

      boolean sinTocar=0;  
      for(int i=0;i<60;i++)
        {
          if(vectorTeclaPresionada[i]==0)
            {
              sinTocar=1;
            }
          else
            {
              sinTocar=0;
              i=60;  
            }
        }
      
    if(distinto==1)
      {   
      
       //if (sinTocar==1) //si no se presiona teclas y hay notas debería haber error
        //{
        sumatoriaError++;
        //}
      
      }
     else
      {
        if(sinTocar==0)
          {
            sumatoriaCorrecto++;
          }
         
      }

    }                  
